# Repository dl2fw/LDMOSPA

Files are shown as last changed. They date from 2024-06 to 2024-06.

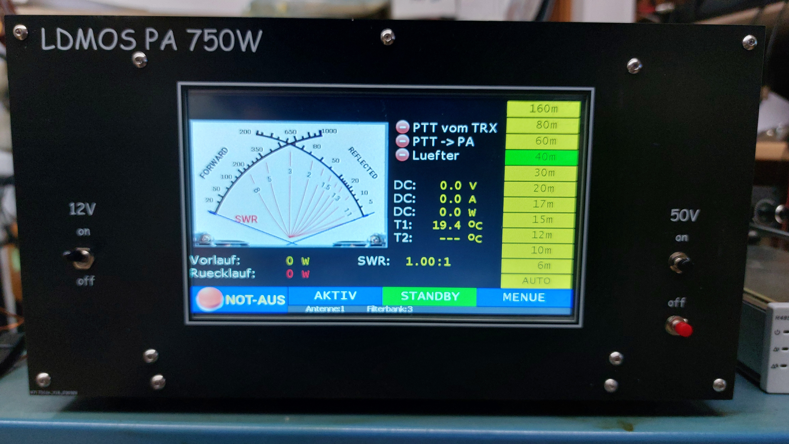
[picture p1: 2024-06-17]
images/20240617_192059.jpg

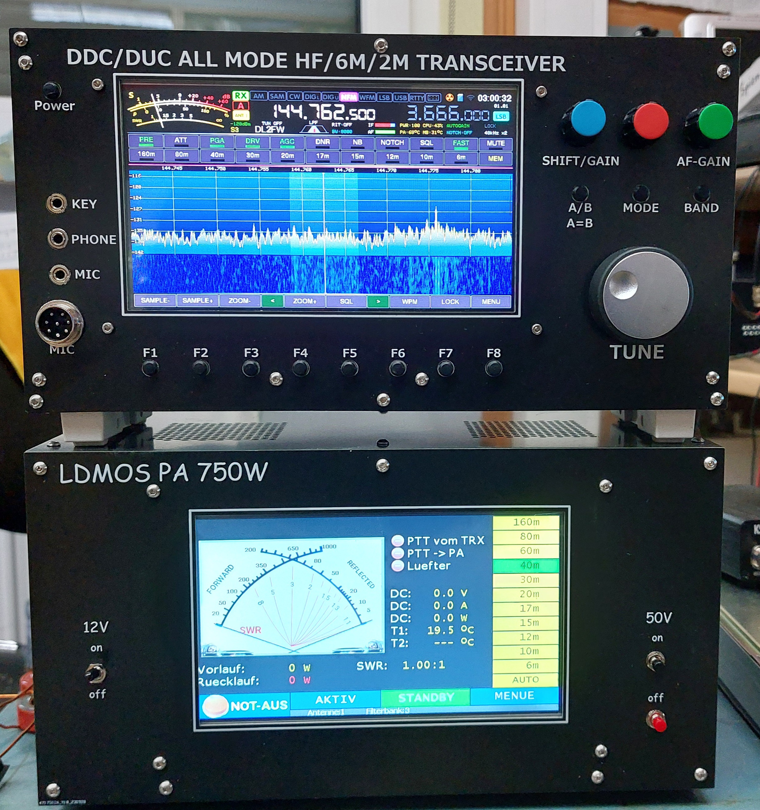
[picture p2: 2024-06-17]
images/20240617_192318.jpg

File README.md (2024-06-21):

# LDMOSPA
LDMOS PA based on the design of DJ0ABR - case from PCB Material<br>
Output power 750 or 1500 Watt - depends on if you use 1 or 2 double mosfets<br>
The PA can be either water or air cooled - the case makes both possible - I prefer the water cooled version<br>
The front has the same size as DB5AT's Wolf SDR case based on PCB Material<br>
All gerbers are available here<br>
I tried to gather all schematics and gerbers for the PA<br>
Also BOMS for Digikey, Reichelt and Aliexpress are in the BOM folder<br>
The water cooler is a ready available one (Digikey,...) for app. 65€<br>







Link to dj0abr's homepage with further information in german and english:

https://www.dj0abr.de/

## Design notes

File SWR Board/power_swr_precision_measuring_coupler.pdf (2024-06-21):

2022/01/31 19:27 | 1/14 | Power / SWR precision measuring coupler

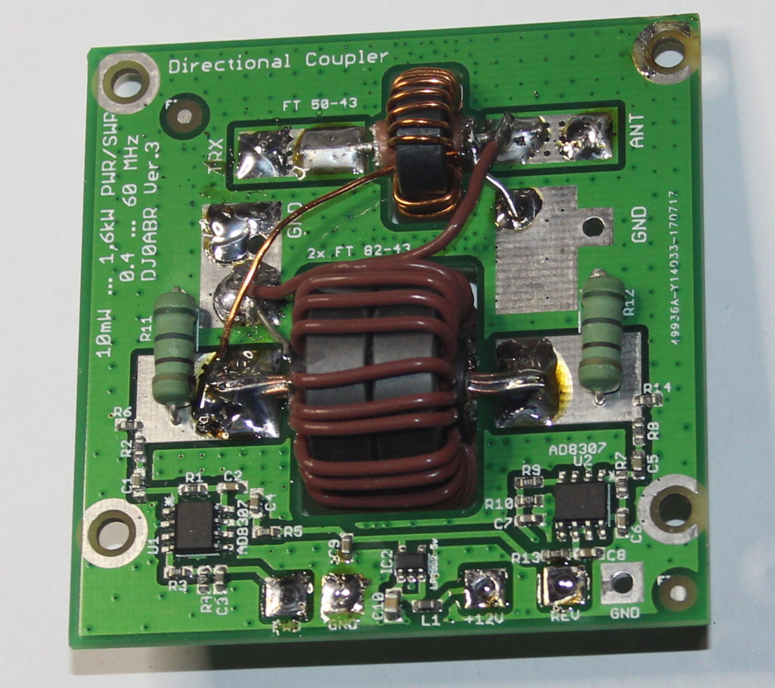
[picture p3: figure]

DJ0ABR Projects - http://projects.dj0abr.de/

# Power / SWR precision measuring coupler

0,4 ... 70 MHz

100mW ... 2kW

This second version of a Sontheimer/Frederik coupler was developed as part of our 1kW LDMOS-PA project. The focus of this coupler is a wide power range and a wide frequency range. Measurements of 1mW were omitted, but the coupler is optimized up to more than2kW, so it is well equipped for power amplifiers.

Very important was also the simple construction. The annoying mechanical work for the production of tinplate housings had to be omitted absolutely.

Technical data of this shortwave power/SWR coupler:

Power range: 100 mW to 2 kW
Frequency range: 0.4 MHz to 60 MHz (630m to 6m band), with reduced accuracy also usable in 4m band
directivity on all bands > 30dB (on 70 MHz >20dB)
built on a single board which also contains the two toroidal cores
two AD8307 are used, one for the forward power and one for the reverse power
the circuit works completely balance-free and is therefore easy to build up

the circuit of the first version turned out to be optimal, therefore it was taken over unchanged. The main changes were the mechanical construction and the dimensioning of the toroidal cores. Due to a specially calculated circuit board layout, a good adaptation could be achieved even without a housing.

The directivity and thus the resolution of the SWR measurement is so accurate that even the

Last update: 2021/05/12 16:11 | en:pwrswr:pwrswr_overview http://projects.dj0abr.de/doku.php?id=en:pwrswr:pwrswr_overview
http://projects.dj0abr.de/ | Printed on 2022/01/31 19:27

influence of adapter plugs (PL-N etc) can be measured clearly. Also the quality of coax cables can be measured. Of course, this requires a precise dummy load (with exactly 50 ohms).

toroidal cores, size:

this coupler uses 2 toroidal cores and is therefore alignment free.

Ringcore-1: this sits directly above the connection transceiver antenna. This line is passed through the core once (so means 1 turn). This core measures the current which flows from the transceiver to the antenna. In this core almost no power is converted. A tiny amount of power is coupled in through one turn and coupled out through the 24 secondary turns. Since no power is converted, this core can remain very small. We have chosen the FT50-43 from Amidon.

Ring core-2: this is connected with its 24 turns directly to the antenna output of the coupler. Depending on inductance and transmitting power a considerable current flows here which leads to a heating of this toroid due to copper and iron losses. Since the coupler should work up to 2 kW, 2 pieces of Amidon FT82-43 are glued on top of each other and wound together.

For the symmetry of the coupler only the number of turns is important (here it is 24 Wdg. each) the core size has no influence, so you can work with one FT50 and two FT82.

toroidal cores, material:

To cover such a wide range from 0.4 MHz to 60 MHz is always a compromise. There is simply no toroid that has consistent characteristics over this range.

We tested countless cores and finally decided on the Amidon Material 43. This has only a slight drop at 400 kHz, a little more drop at 52 MHz, but offers an excellent straight frequency response in the interesting range from 160m to 10m.

If you are mainly interested in the lower bands, you can use material 77, which goes well from 0.1 MHz to 21 MHz, above that it breaks in.

The 6m band takes a special position. One could still get a little more out with the material 61, however, on 50 MHz the mechanical construction already has an extreme effect. The approach of the hand to the toroidal cores already influences the measurement. Nevertheless, with material 43, we still have measurement accuracies for SWR that are better than most commercial SWR meters.

Number of turns:

basically you should use as many turns as possible, for 2 reasons: first, the precision of the coupler increases with the number of turns and second, we need as high an inductance as possible for toroid-2 so that its current drops and it gets less hot.

However, the other side of the coin is that as the number of turns increases, the upper cutoff frequency of the coupler decreases. There are also resonances between the toroidal inductance and the parasitic capacitances of the structure, which are in the range between 30 and 100 MHz. If one makes too many turns, this resonance comes down and disturbs the measurement in the 6m band. In

2022/01/31 19:27 | 3/14 | Power / SWR precision measuring coupler
many tests it has been found that 24 turns work optimally.

Measuring amplifier:

the very proven Analog Devices AD8307 is used. The achievable measuring range of less than 10mW up to more than 2kW is unbeatable. Unfortunately this IC is very expensive and is traded between 10 and 13 Eur per piece. Since I don't trust the Far East fakes, we bought a large quantity in a collective order for a quite good price, so you can get these ICs HERE quite cheap.

Circuitry of the toroidal cores:

on top is toroid-1 directly between transmitter and antenna, it measures the current through the antenna cable. The bottom core is toroid-2, it measures the voltage at the antenna connector.

Together with the 50 Ohm resistors they form the measuring bridge. The AD8307 is connected to the two output lines.

There are 56 Ohm resistors inserted. Together with the input resistance of the AD8307 circuit, the required 50 ohms are obtained. An adjustment to 50 ohms would be possible, but in practice it is not feasible because the accuracy of the usual measuring instruments is not sufficient for this. A directivity of better than 30dB can always be achieved without any adjustment and thus a SWR resolution of a few hundredths !

Winding scheme in detail:

there is nothing more confusing than the correct winding scheme. But it has to be right. The layout is set to this winding scheme, if you do it wrong then you quickly lose 10dB of directivity.

To keep the overview, here is a photo series with detail shots. This is just to show in which direction the cores are wound. If you look closely, you can see that the FT50 and FT82 cores have opposite winding directions.

Number of windings: 24 (for both cores)

Wire:

The FT50-43 is wound with CuL 0,63mm diameter (any wire between 0,35 and 0,65mm can be used)

The two FT82-43 glued together are wound with CuL 1.0mm diameter (any wire between 0.60 and 1.2mm can be used)

In the pictures the FT82-43 pair is wound with Teflon wire 0,34qmm (1mm outer diameter). This is easier than using CuL wire, because there is no danger to scratch the varnish of the wire (available here).

first the small FT50-43:

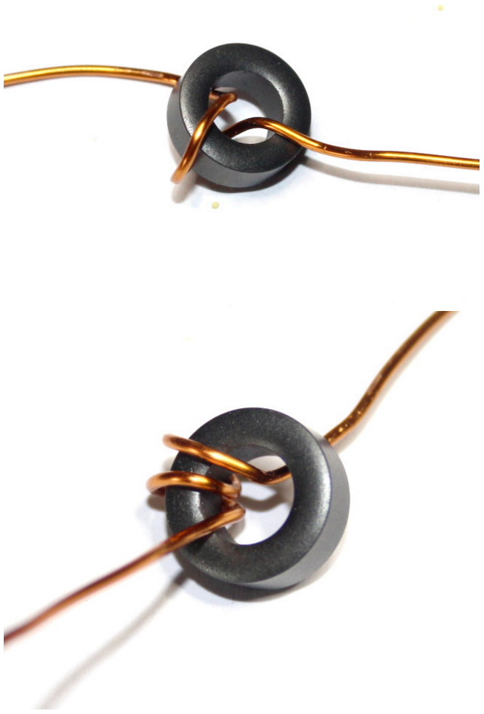
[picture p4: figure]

then the scheme for the pair FT82-43:

of course a FT82-43 double pack is wound, here for a better overview the winding scheme on a single core.

2022/01/31 19:27 | 5/14 | Power / SWR precision measuring coupler

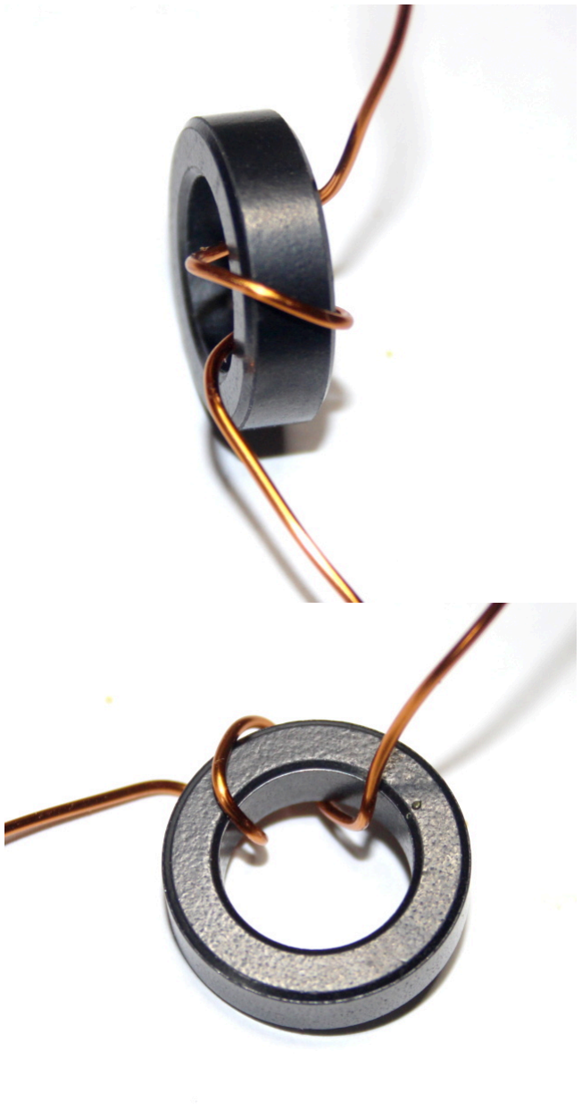
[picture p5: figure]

AD8307 Measurement circuit:

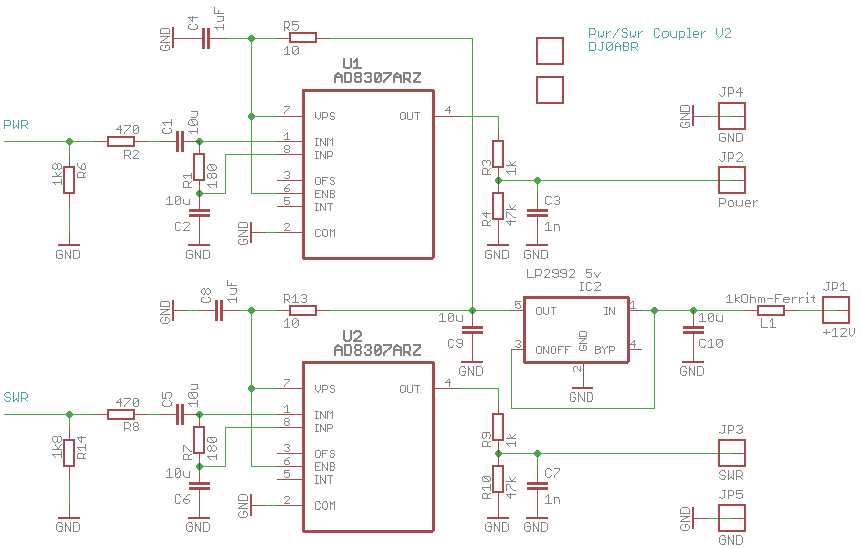
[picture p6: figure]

the 1.8kOhm resistor is in parallel with the 56 Ohm resistor (schematic above), together with R8 and the input resistor of the AD8307 you get 50 Ohm.

At the solder terminals JP2 and JP3 a voltage is output which corresponds to the forward and reverse power. This voltage is in the range of 0.5 to 2 volts and therefore fits to the different display boards.

Board and assembly diagram:

the two cutouts are used to hold the toroidal cores.

Assembly instructions:

this is how the assembled board looks like, still without toroidal cores:

2022/01/31 19:27 | 7/14 | Power / SWR precision measuring coupler

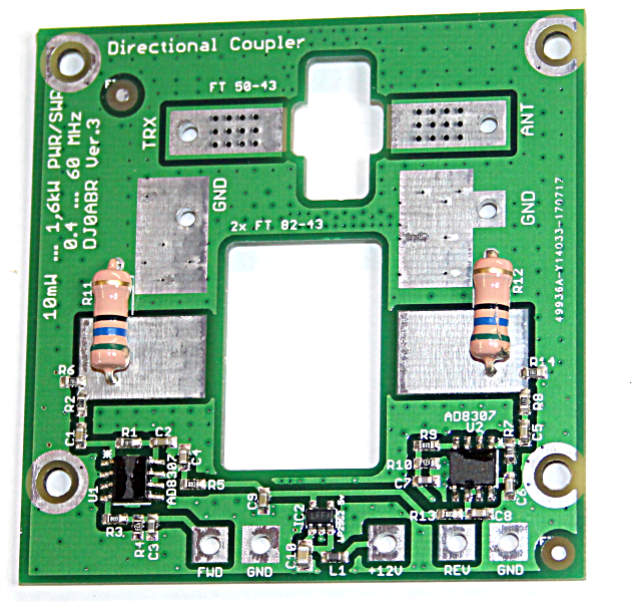
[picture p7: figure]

Preparation of the toroidal cores:

24 turns of CuL (approx.) DM 0.35 mm are wound on the FT50-43. You can use wire diameters from 0.3 to 0.65mm.

Two FT82-43 are glued together and then wound with 24 turns of CuL (approx.) DM 0.63 mm, wire diameters from 0.6 to 1.0 mm fit here.

For better shielding (only with this the coupler can be used on 6m and 4m) the wires through the toroidal cores must be made of coaxial cable. To avoid short-circuiting the voltage to be measured, the shield of this coaxial cable must be connected to ground on one side only.

Prepare the following small pieces of cable:

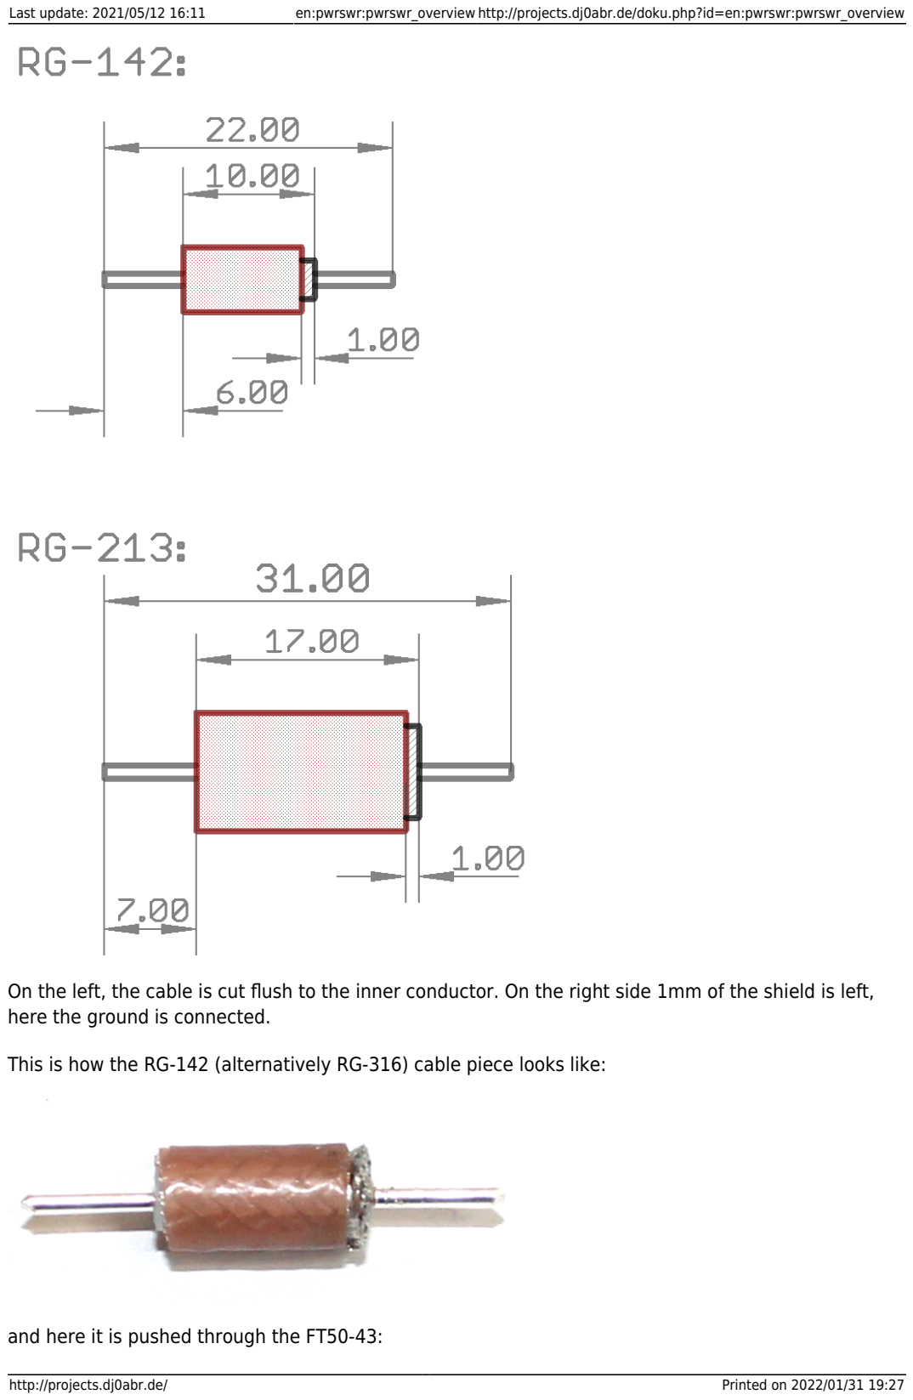
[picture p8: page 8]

On the left, the cable is cut flush to the inner conductor. On the right side 1mm of the shield is left, here the ground is connected.

This is how the RG-142 (alternatively RG-316) cable piece looks like:

and here it is pushed through the FT50-43:

2022/01/31 19:27 | 9/14 | Power / SWR precision measuring coupler

and the RG-213 (alternatively Aircell-7) cable piece:

Detail photos of the installation of the cores and their connection:

at the end of this post there are several detail photos. Please connect the cores exactly according to them.

Checking the coupler:

this coupler does not need any adjustment, because the measurement is done by the AD8307 which are very accurate. Of course the coupler has a certain division ratio which is given by the selected resistors. This ratio as well as always existing component tolerances are performed by the display boards by software.

What we still do to test the board is to measure the directivity because we want to be better than 30dB:

For this we connect

1. a 12V power supply
2. a voltmeter to the output FWD
3. a voltmeter to the output REV
4. a KW radio to the TRX connector
5. a 50 Ohm dummyload as accurate as possible to the ANT connector

the requirements for the dummy load are high, it should be in the range of 49.5 to 50.5 ohms. Mostly dummyloads are not that accurate so we will measure a worse directivity than the coupler actually offers. If you want to know exactly, you have to measure 50 Ohm resistors precisely and also know the accuracy of the ohmmeter.

To measure the directivity we proceed like this:

1. Set radio to 7MHz and transmit at 5 watts in FM (continuous carrier).
2. Measure the voltage at FWD (in millivolts).
3. Set radio to 7MHz and transmit at 100 watts in FM (continuous carrier).
4. Measure the voltage at FWD (in millivolts).
5. Measure the voltage at REV (in millivolts).

Once you have measured the three voltages, enter them into this Excel sheet and you can read the directivity. Yellow lines are to be entered, the others are calculated.

We use 7 MHz because KW dummy loads become more and more inaccurate at higher frequencies. If you use a 50 Ohm RF resistor you are better off, but measure the accuracy here too. Furthermore, the dummy load must be connected short, with a good coaxial cable and no adapter plugs may be used because all this makes the directional sharpness look worse than it is.

Note on the measurement setup:

If you want to determine the directivity of a coupler exactly, you have to meet the following requirements:

solder a 50 Ohm RF resistor directly and without cable to the output pins of the PCB (cable and connector would already have an SWR of >1.05 and would therefore falsify the measured value).
measure the 50 Ohm RF resistor (there are many resistors that have high tolerances), it should deviate by a maximum of 0.5 Ohm, but this already pushes the directivity to no 40dB. Please pay attention to the tolerance of the resistance meter.
do not hold out probes or other measuring devices, since their capacitance worsens the measurement of the directivity
if you want to measure the power at the same time, build an adapted decoupling as described in the following link

Detailed images:

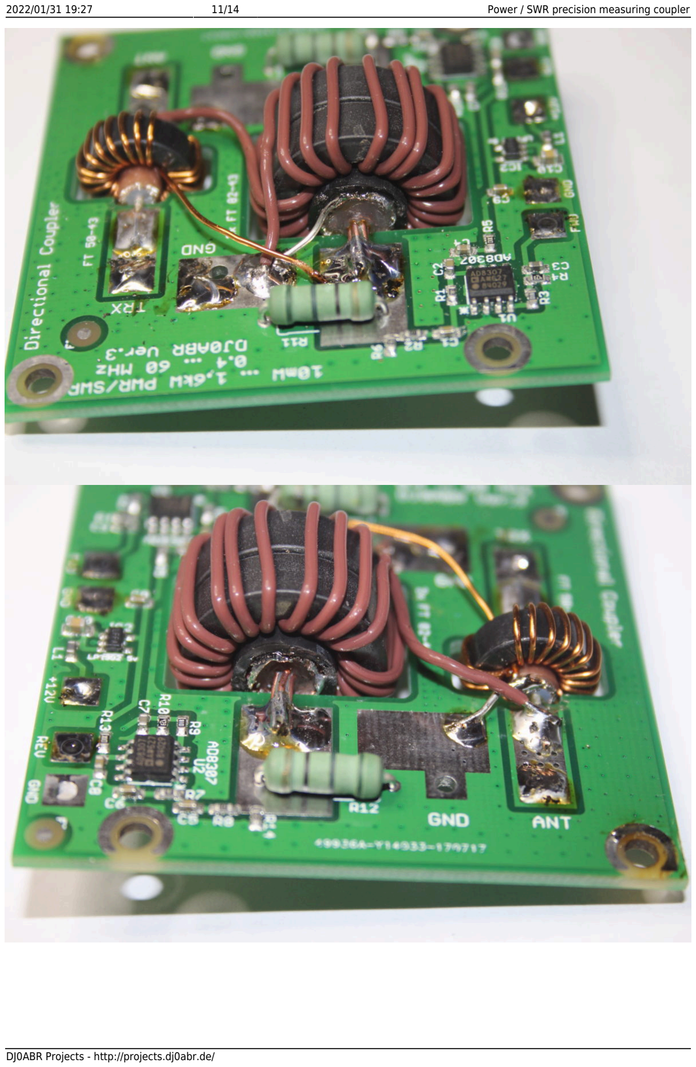
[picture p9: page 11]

2022/01/31 19:27 | 11/14 | Power / SWR precision measuring coupler

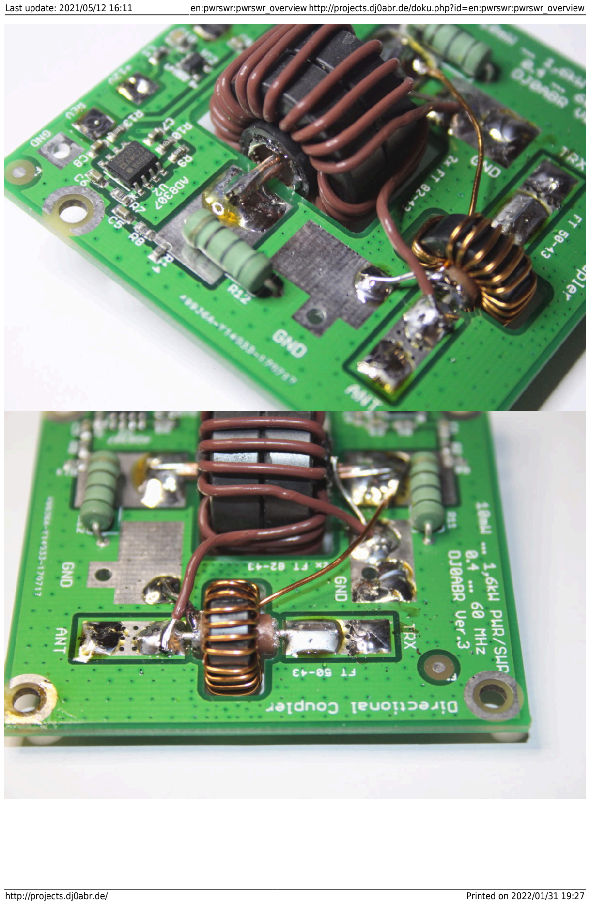
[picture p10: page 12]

2022/01/31 19:27 | 13/14 | Power / SWR precision measuring coupler

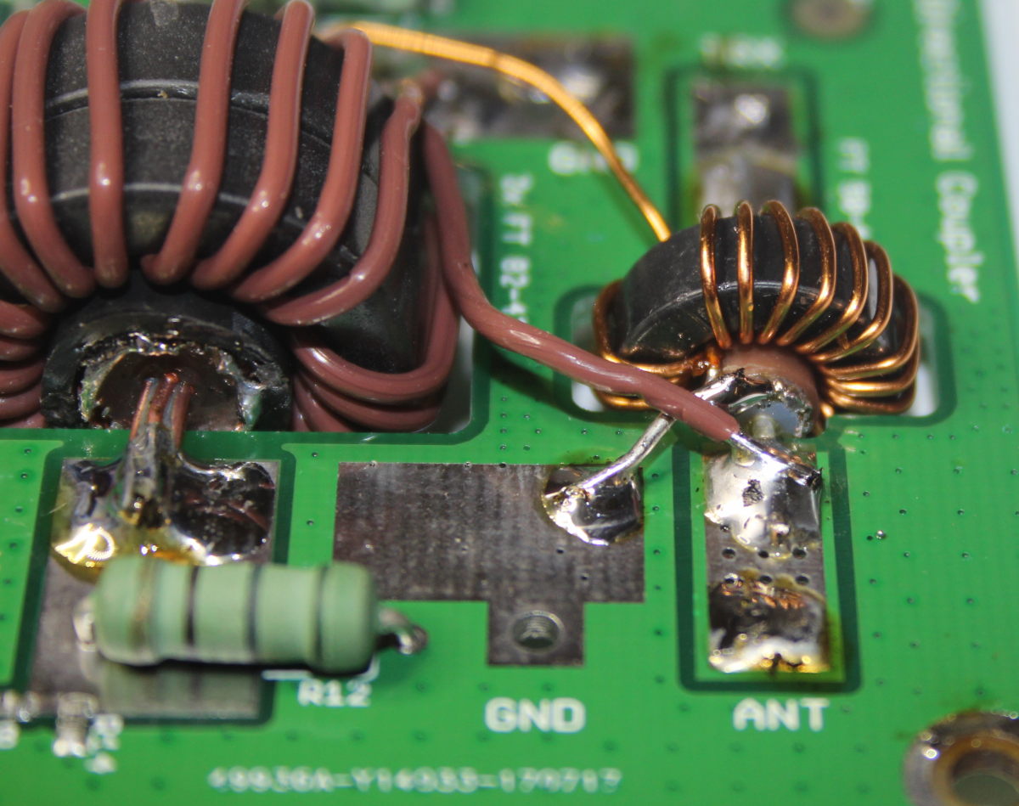
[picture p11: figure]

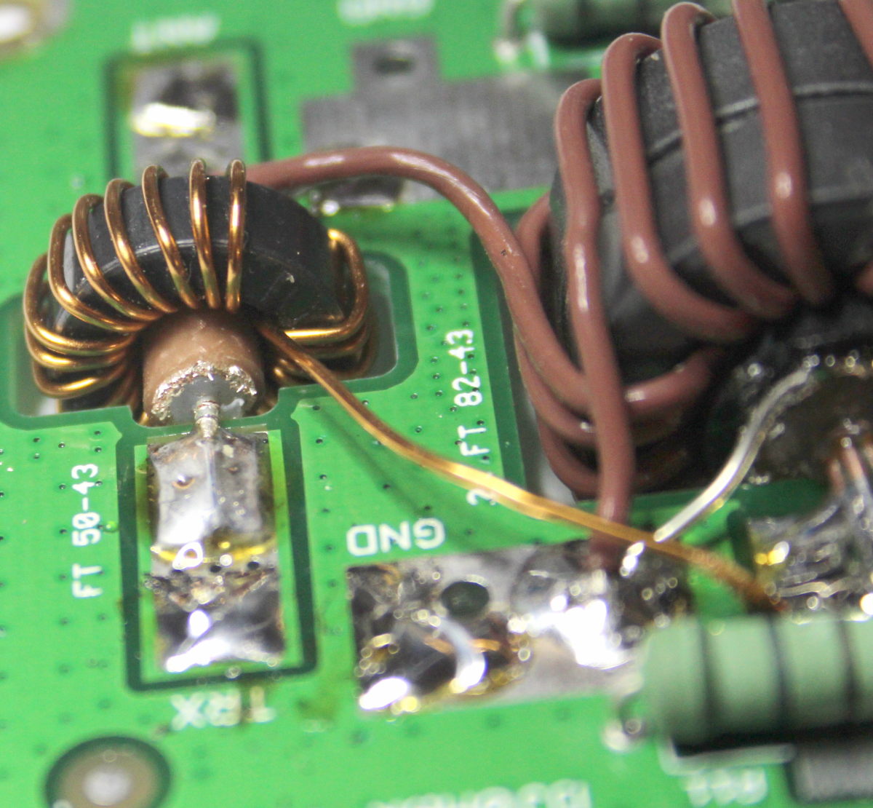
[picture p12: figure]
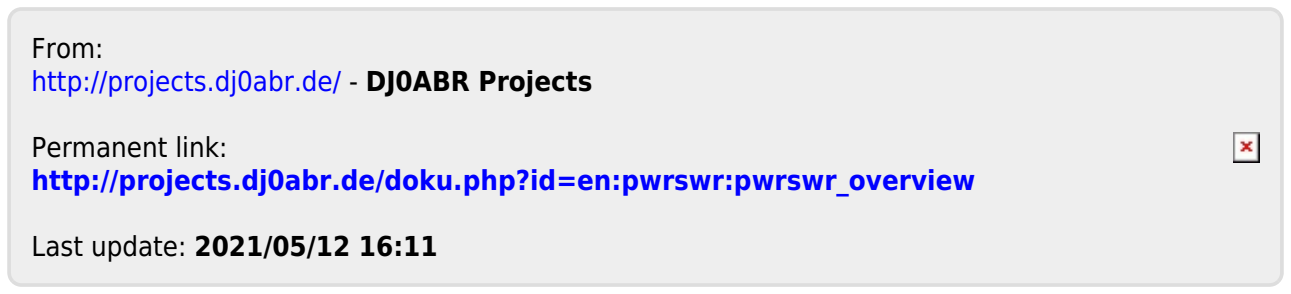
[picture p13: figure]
From: http://projects.dj0abr.de/ - DJ0ABR Projects; Permanent link: http://projects.dj0abr.de/doku.php?id=en:pwrswr:pwrswr_overview; Last update: 2021/05/12 16:11

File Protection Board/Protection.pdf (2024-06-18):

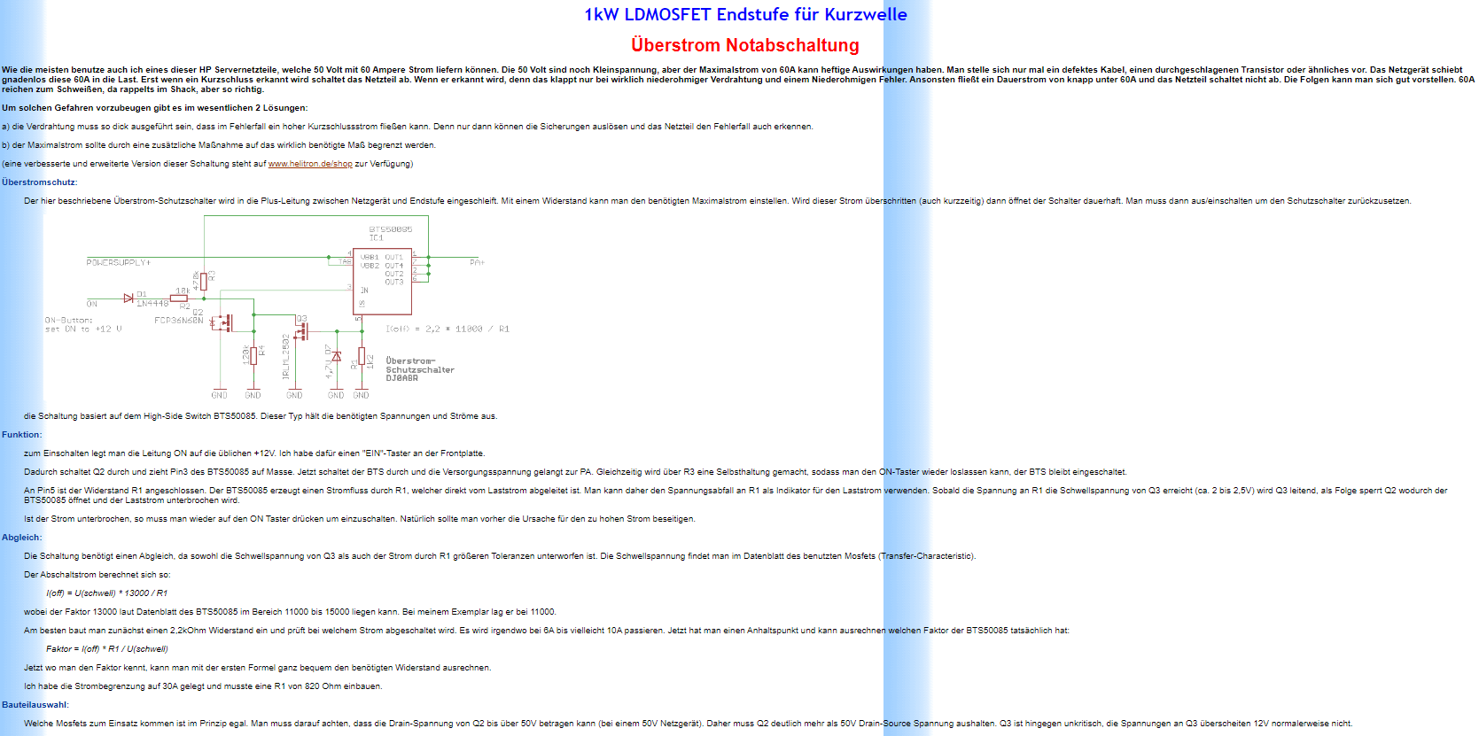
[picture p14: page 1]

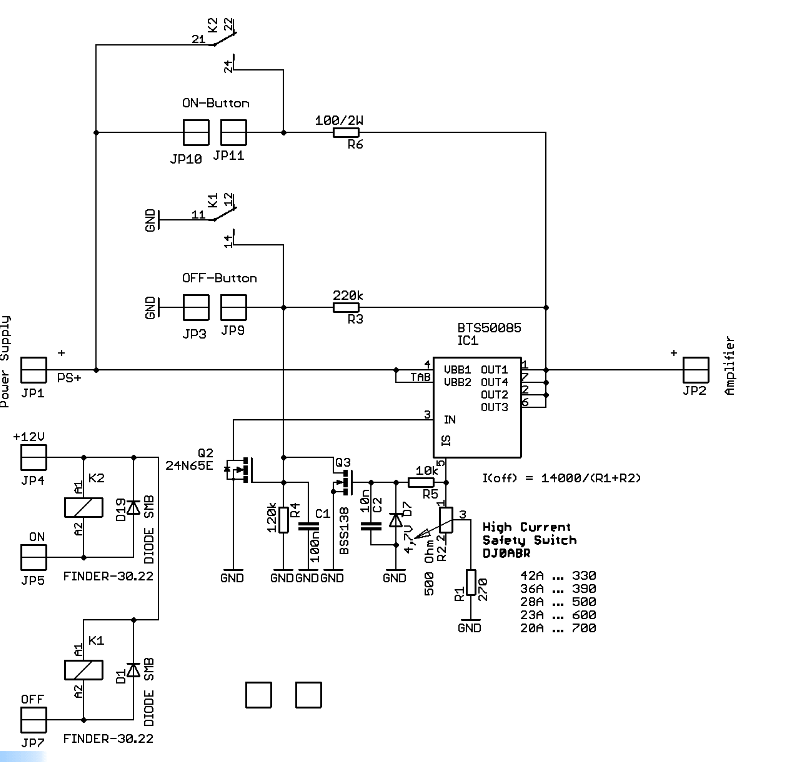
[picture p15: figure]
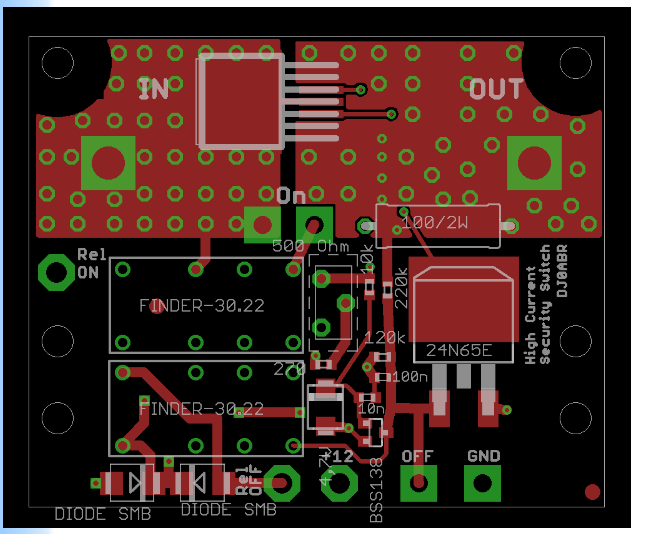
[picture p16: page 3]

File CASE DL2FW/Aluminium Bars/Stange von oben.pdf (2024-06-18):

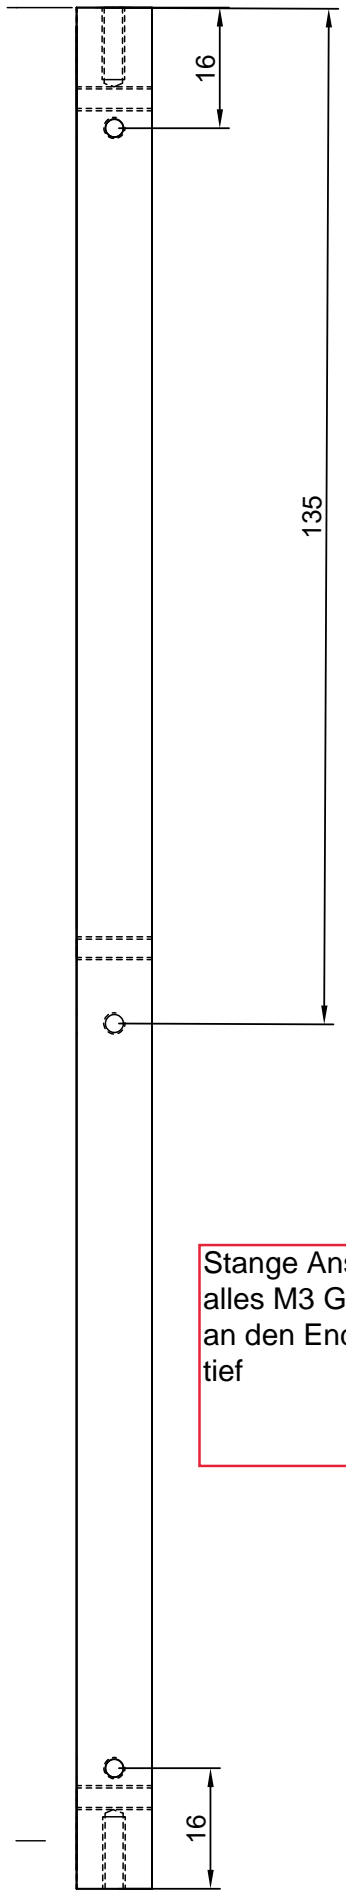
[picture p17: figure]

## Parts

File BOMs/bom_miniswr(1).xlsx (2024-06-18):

QTY |  |  |  |  |  | Reichelt | Digikey | Preis | Gesamt
1 | 10u/25 | cer. Cap. Multilayer | SMD 0805 | C10 |  | 1276-6454-1-ND |  | 0.16 | 0.16
2 | 56/2W | Resistor | 0411/12 | R11, R12 |  | 2W METALL 56 |  | 0.14 | 0.28
2 | FT82-43 | Ferrite Core |  |  | Amidon | AMI FT-82-43 |  | 2.25 | 4.5
1 | FT50-43 | Ferrite Core |  |  | Amidon | FT 50-43 |  | 0.99 | 0.99
5 | 10u | cer. Cap. Multilayer | SMD 0603 | C1, C2, C5, C6, C9 |  | KEM X5R0603 10U |  | 0.13 | 0.65
1 | LP2992 5v | voltage regulator 5V | SOT23-5 | IC2 |  | LP 2992 IM5-5.0 |  | 2.1 | 2.1
2 | AD8307ARZ | log.Amp. | SOIC8 | U1, U2 | Alieexpresss
2 | 1k | SMD resistor 0,1W | SMD 0603 | R3, R9 |  | SMD-0603 1,0K |  | 0.04 | 0.08
2 | 1k8 | SMD resistor 0,1W | SMD 0603 | R6, R14 |  | SMD-0603 1,8K |  | 0.04 | 0.08
2 | 10 | SMD resistor 0,1W | SMD 0603 | R5, R13 |  | SMD-0603 10 |  | 0.04 | 0.08
2 | 180 | SMD resistor 0,1W | SMD 0603 | R1, R7 |  | SMD-0603 180 |  | 0.04 | 0.08
2 | 470 | SMD resistor 0,1W | SMD 0603 | R2, R8 |  | SMD-0603 470 |  | 0.04 | 0.08
2 | 47k | SMD resistor 0,1W | SMD 0603 | R4, R10 |  | SMD-0603 47K |  | 0.04 | 0.08
2 | 1n | cer. Cap. Multilayer | SMD 0603 | C3, C7 |  | WAL 0603B102K500 |  | 0.02 | 0.04
2 | 1uF | cer. Cap. Multilayer | SMD 0603 | C4, C8 |  | X5R-G0603 1,0/25 |  | 0.13 | 0.26
1 | 1kOhm-Ferrit |  | SMD 0603 | L1 | or similar |  | 732-1592-1-ND | 0.16 | 0.16
1 | PCB | 62*61mm |  |  | JLCPCB |  | 5 Pieces |  | 2
 |  |  |  |  |  |  |  |  | 11.62

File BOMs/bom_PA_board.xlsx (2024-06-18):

 |  |  |  |  | Reichelt | Digikey | Preis | Summe
Qty | Device | Type | Package | Parts
2 | 250 ohms | Trimm Poti | RM 5 / 2,5mm | R16, R25 | 64Y-200 |  | 1.6 | 3.2
2 | 470uF/63V | electrolytic cap. | 12.5 (Dia.) x 20mm | C40, C41 | EB-A 470U 63 |  | 0.99 | 1.98
1 | Lesitungsrelais 12V G5RL-1E-HR-12V |  | G2RE | K3 | G5RL-1E-HR 12DC |  | 1.99 | 1.99
1 | IRLML6401 | P-CHANNEL MOS FET | SOT23 | T7 | IRLML 6401 |  | 0.82 | 0.82
1 | 10u | ceramic multilayer capacitor X7R | SMD 0603 | C48 | KEM X5R0603 10U |  | 0.13 | 0.13
3 | 10n | ceramic multilayer capacitor X7R | SMD 0603 | C6, C10, C56 | KEM X7R0603 10N |  | 0.03 | 0.09
2 | 1k | resistor | SMD 0603 | R6, R11 | SMD-0603 1,0K |  | 0.04 | 0.08
2 | 10k | resistor | SMD 0603 | R17, R18 | SMD-0603 10K |  | 0.04 | 0.08
2 | 270 | resistor | SMD 0603 | R13, R24 | SMD-0603 270 |  | 0.04 | 0.08
2 | 47 | resistor | SMD 0603 | R12, R23 | SMD-0603 47 |  | 0.04 | 0.08
2 | 470 | resistor | SMD 0603 | R7, R14 | SMD-0603 470 |  | 0.04 | 0.08
2 | 5k6 | resistor | SMD 0603 | R10, R22 | SMD-0603 5,6K |  | 0.04 | 0.08
2 | 560 | resistor | SMD 0603 | R9, R21 | SMD-0603 560 |  | 0.04 | 0.08
2 | 100u/63 | electrolytic cap. | Dia 11 max. | C20, C21 | TG-V 100U 63 |  | 1.1 | 2.2
3 | 100n | ceramic multilayer capacitor X7R | SMD 0603 | C4, C42, C54 | WAL 0603B104K500 |  | 0.02 | 0.06
5 | 1u | ceramic multilayer capacitor X7R | SMD 0603 | C3, C5, C53, C55, C57 | X5R-G0603 1,0/25 |  | 0.13 | 0.65
2 | 10u | ceramic multilayer capacitor X7R | SMD 0805 | C9, C47 | X5R-G0805 10/16 |  | 0.05 | 0.1
2 | 10n/500V | caramic capacitor 450V | SMD 1206 | C1, C2 |  | 311-1510-1-ND | 0.25 | 0.5
14 | 10n/500V | ceramic multilayer capacitor X7R | SMD 1210 | C30, C31, C32, C33, C34, C35, C36,C37, C38, C39, C43, C44, C45, C46 |  | 478-KGM32ER72H103KUCT-ND | 0.63 | 8.82
8 | 100n/600V | ceramic multilayer capacitor X7R | SMD 1812 | C12, C13, C17, C18, C49, C50, C51, C52 |  | 478-KGM43FR72J104KVCT-ND | 0.64 | 5.12
4 | 10n/1kV | ceramic multilayer capacitor X7R | SMD 1812 | C8, C11, C15, C16 |  | 1812AC103KAT1A | 0.49 | 1.96
8 | 120p/3kV | ceramic multilayer capacitor C0G | SMD 1812 | C22, C23, C24, C25, C26, C27, C28, C29 |  | CGA8L1C0G3F121K160KA | 0.75 | 6
2 | 1u/250V | ceramic multilayer capacitor X7R | SMD 1812 | C14, C19 |  | C1812X105K251T | 1 | 2
8 | DIODE SMB | standard Schottky Diode | SMB | D4, D5, D8, D9, D12, D13, D15, D16 |  | S2MFSCT-ND | 0.41 | 3.28
2 | NTC0805J5K0 | NTC | SMD 0805 | R8, R15 |  | 1712-NTC0805J5K0CT-ND | 1.2 | 2.4
12 | 10 | resistor | SMD 1206 | R26, R27, R28, R29, R30, R31, R32,R33, R34, R35, R36, R37 |  | 541-10.0UCT-ND | 0.37 | 4.44
2 | 10/2W | resistor | SMD 2512 | R4, R5 |  | A121124CT-ND | 0.62 | 1.24
1 | 100/2W | resistor | SMD 2512 | R3 |  | CRM2512-FX-1000ELFCT-N | 0.5 | 0.5
4 | 22/2W | resistor | SMD 2512 | R1, R2, R19, R20 |  | CRM2512-JW-220ELF | 0.57 | 2.28
1 | LP2992 - 5V | 5V voltage regulator | SOT23-5 | IC2 |  | LP2992AIM5X-5.0/NOPBCT-ND | 1.5 | 1.5
2 | 4,7V | zener diode | SMA | D3, D7 |  | KDZVTFTR4.7BCT-ND | 0.44 | 0.88
1 | 6,2V/1W | zener diode | SMA | D14 |  | KDZVTFTR6.2BCT-ND | 0.44 | 0.44
2 | 8,2V | zener diode | SMA | D2, D6 |  | SMAJ4738A-TPCT-ND | 0.38 | 0.76
2 | SMBJ15A | TVS protection diode | SMA | D10, D11 |  | SMBJ15ALFCT-ND | 0.37 | 0.74
1 | BLF188 | BLF188XR (or two BLF188XR) | BLF188 | T1, T2 |  | xxx |  | 0
1 | 12V Relais | Relais 12V Kontakt: DPDT |  | K2 |  | PB1632-ND | 3.85 | 3.85
8 | Ferrite Core |  | Laird 28B1020-100 |  |  | 240-2081-ND | 2.47 | 19.76
1 | Ferrite Core | Input Transformer | Laird 28B0562-100 | TR1 |  | 240-2607-ND | 0.54 | 0.54
1 | Ferrite Ring | Ub EMI suppression | any code possible Dia abt. 30mm | L1 |  | 732-1536-ND | 5.84 | 5.84
 | Water Cooler |  |  |  |  | CP4A-114B-108E-ND |  | 80.43
 | Copper Plate |  | 10mmm thick
 | Power Mosfet | BLF188 or MRFX1K80 | app. 150€
 | Board |  | Size: 116*200mm | select high copper coating! |  | from JLCPCB | 5 Pieces | 30.9
 |  |  |  |  |  |  | Sum | 188.79 | €

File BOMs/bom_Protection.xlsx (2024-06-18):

QTY |  |  |  | Reichelt | Digikey | Preis | Gesamt
1 | 270 | R0603 | R1 | SMD-0603 270 |  | 0.04 | 0.04
1 | 500 Ohm | MINIPOTI | R2 | 64Y-500 |  | 1.2 | 1.2
1 | 220k | R0603 | R3 | SMD-0603 220K |  | 0.04 | 0.04
1 | 120k | R0603 | R4 | SMD-0603 120K |  | 0.04 | 0.04
1 | 10k | R0603 | R5 | SMD-0603 10K |  | 0.04 | 0.04
1 | 100/2W | P0613/15 | R6 | 2W METALL 100 |  | 0.15 | 0.15
1 | 100n | C0603K | C1 | WAL 0603B104K500 |  | 0.04 | 0.04
1 | 10n | C0603K | C2 | KEM X7R0603 10N |  | 0.04 | 0.04
1 | 4,7V | SMA | D7 | BZV 55-C4V7 NXP |  | 0.1 | 0.1
1 | BSS138 | SOT23 | Q3 | BSS 138P NXP |  | 1 | 1
1 | 24n65e |  |  |  | 742-SIHB24N65EFT1-GE3CT-ND | 5.8 | 5.8
2 | Relais |  |  | Finder 30-22 12V
1 | BTS50085 | DPAK |  | Aliexpress, digikey,…

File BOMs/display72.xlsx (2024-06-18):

QTY | Value | Device | Package | Parts | Supplier | Order No. | Reichelt | Digikey | Preis | Gesamt
5 | 5 1N4448 | SMD Diode | SOD523 | D2, D3, D4, D5, D16 |  |  | 1N 4448W7F DII |  | 0.09 | 0.45
1 | 1 50k | MINIPOTI-S | MINIPOTI | R90 |  |  | 64Y-50K |  | 1.6 | 1.6
4 | 1 Pinheader 2x4 | Pinheader 2x4 | RM 2,54 | JP7 |  |  | BKL 10120173 |  | 1 | 4
4 | 1 Pinheader 1x6 | Pinheader 1x6 | RM 2,54 | ST3 |  |  | BKL 10120513 |  | 1 | 4
1 | Connector 2x20 | Fischer | DSP1 1 |  |  |  | BKL 10120963 |  | 1.8 | 1.8
1 | 100u/16 | electrolytic capacitor | E2,5-7 | C1 |  |  | HA-V 100U 16 |  | 0.5 | 0.5
7 | 7 N-CH_MOSFET | standard Nch Mosfet (Vgs must be <= 2.5v, so it switches with 3,3v logic. Example: IRLML2502) | SOT23 | Q2, Q3, Q10, Q13, Q14, Q15, Q16 |  |  | IRLML 2502 |  | 0.27 | 1.89
5 | 5 10u | standard chip capacitor | SMD 0603 | C6, C7, C8, C46, C50 |  |  | KEM X5R0603 10U |  | 0.13 | 0.65
14 | 14 10n | standard chip capacitor | SMD 0603 | C5, C33, C34, C35, C36, C37, C38, C49, C51, C52, C85, C86, C87, C89 |  |  | KEM X7R0603 10N |  | 0.03 | 0.42
1 | 1 MAX3232 | RS232 driver | SO16 | IC12 |  |  | MAX 232 CSE SMD |  | 1.39 | 1.39
1 | 1 OKI-78SR-5/1.5-W36H-C | 12V→5V switching reg. | THT 3pin | IC2 |  |  | R-78B50-15L |  | 14 | 14
19 | 19 1k | 0,1W standard SMD resistor | SMD 0603 | R32, R33, R43, R45, R46, R47, R48, R49, R50, R76, R77, R78, R79, R80, R81, R89, R110, R112, R114 |  |  | SMD-0603 1,0K |  | 0.04 | 0.76
1 | 1 1M | 0,1W standard SMD resistor | SMD 0603 | R35 |  |  | SMD-0603 1,0M |  | 0.04 | 0.04
8 | 8 100 | 0,1W standard SMD resistor | SMD 0603 | R4, R5, R6, R7, R8, R9, R39, R91 |  |  | SMD-0603 100 |  | 0.04 | 0.32
12 | 12 100k | 0,1W standard SMD resistor | SMD 0603 | R40, R41, R53, R54, R55, R56, R58, R59, R95, R109, R111, R113 |  |  | SMD-0603 100K |  | 0.04 | 0.48
11 | 11 10k | 0,1W standard SMD resistor | SMD 0603 | R30, R31, R34, R82, R88, R96, R97, R98, R99, R100, R115 |  |  | SMD-0603 10K |  | 0.04 | 0.44
1 | 1 2k2 | 0,1W standard SMD resistor | SMD 0603 | R102 |  |  | SMD-0603 2,2K |  | 0.04 | 0.04
1 | 1 220 | 0,1W standard SMD resistor | SMD 0603 | R25 |  |  | SMD-0603 220 |  | 0.04 | 0.04
1 | 1 22k | 0,1W standard SMD resistor | SMD 0603 | R75 |  |  | SMD-0603 22K |  | 0.04 | 0.04
1 | 1 680 | 0,1W standard SMD resistor | SMD 0603 | R103 |  |  | SMD-0603 680 |  | 0.04 | 0.04
2 | 2 8k2 | 0,1W standard SMD resistor | SMD 0603 | R85, R86 |  |  | SMD-0603 8,2K |  | 0.04 | 0.08
5 | 5 SS110B | SMD Diode | MELF | D9, D10, D11, D12, D13 |  |  | SS 110 (https://www.reichelt.de/schottkydiode-100-v-1-a-do-214ac-sma-ss-110-p146603.html?&trstct=pos_0&nbc=1) |  | 0.21 | 1.05
6 | 6 1n | standard chip capacitor | SMD 0603 | C53, C56, C59, C111, C112, C113 |  |  | WAL 0603B102K500 |  | 0.02 | 0.12
57 | 57 100n | standard chip capacitor | SMD 0603 | C9, C10, C11, C12, C13, C14, C15, C16, C17, C18, C19, C20, C21, C22, C23, C24, C25, C26, C27, C30, C55, C60, C62, C67, C68, C69, C70, C71, C72, C73, C75, C76, C77, C78, C79, C80, C90, C91, C92, C93, C94, C95, C96, C97, C98, C99, C100, C101, C102, C103, C104, C105, C106, C107, C108, C118, C119 |  |  | WAL 0603B104K500 |  | 0.02 | 1.14
14 | 14 1u | standard chip capacitor | SMD 0603 | C31, C32, C39, C40, C41, C42, C43, C44, C45, C47, C48, C61, C63, C74 |  |  | X5R-G0603 1,0/25 |  | 0.13 | 1.82
9 | 9 1u | standard chip capacitorK | SMD 0603K | C54, C57, C58, C64, C65, C81, C82, C83, C84 |  |  | X5R-G0603 1,0/25 |  | 0.1 | 0.9
6 | 6 10u | standard chip capacitor | C0805 | C2, C3, C4, C29, C116, C117 |  |  | X5R-G0805 10/16 |  | 0.05 | 0.3
1 | 1 10u | standard chip capacitor | C0805K | C88 |  |  | X5R-G0805 10/16 |  | 0.05 | 0.05
1 | 1 OSC 8MHz | Standard 8 MHz crystal oscillat | 7x5mm | OSC1 |  |  | XO91 8,00000 |  | 1.6 | 1.6
1 | 1 10k/0,1% | 0,1W standard SMD resistor | SMD 0603 | R87 |  |  |  | CRT0603-BY-1002ELF | 0.35 | 0.35
34 | 34 1kOhm-Ferrit | 0,1W standard SMD resistor | SMD 0603 | R1, R2, R3, R10, R11, R12, R13, R14, R15, R16, R17, R18, R19, R20, R21, R22, R23, R24, R62, R63, R64, R65, R66, R67, R68, R69, R70, R71, R72, R73, R92, R93, R94, R101 |  |  |  | 732-1592-1-ND | 0.16 | 5.44
2 | 2 390k/0,1% | 0,1W standard SMD resistor | SMD 0603 | R83, R84 |  |  |  | YAG4542CT-ND | 0.3 | 0.6
4 | 4 NTS245SFT1G | SMD Diode | SOD-123FL | D6, D7, D14, D15 |  |  |  | 1727-7479-1-ND | 0.4 | 1.6
1 | 1 IRLML6401 | standard Pch Mosfet (Vgs must be <= 2.5v, so it switches with 3,3v logic. Example: IRLML6401) | SOT23 | Q1 |  |  |  | 785-1001-1-ND | 0.42 | 0.42
1 | INA193AQDBVRQ1 | SOT23-5 |  | IC4 |  |  |  | 296-21443-1-ND | 2.9 | 2.9
5 | 5 IRF3704S | IRF3704S) | D2PACK | Q5, Q6, Q7, Q8, Q9 |  |  |  | IRFS3806TRLPBFCT-ND | 1.29 | 6.45
2 | 2 150141M173100 | Full Color Led | PLCC4 | LED1, LED2 |  |  |  | 732-4998-1-ND | 0.54 | 1.08
5 | 5 TS27L2C | low power OP amp | SO08 | IC5, IC6, IC7, IC8, IC9 |  |  |  | TS27L2CDT | 0.93 | 4.65
1 | 1 LF33CDT-DPAK | 3,3v LDO regulator | DPACK | IC1 |  |  |  | 497-1532-1-ND | 1.46 | 1.46
1 | 1 ADR381 | voltage reference | SOT23 | IC11 |  |  |  | 505-ADR381ARTZ-R2CT-ND | 3.39 | 3.39
5 | 5 100n/200V | standard chip capacitor | C1206K | C28, C109, C110, C114, C115 |  |  |  | 732-12081-1-ND | 0.15 | 0.75
1 | 1 4u7 | standard chip capacitor | SMD 0603 | C66 |  |  |  | 1276-1044-1-ND | 0.09 | 0.09
1 | 1 STM32F427VGT6 or STM32F427VIT6 | uController | LQFP100 | IC13 |  |  |  | 497-14049-ND | 17 | 17
1 | 1 TC7662AEPA | Voltage Converter | SO-8 | U1 |  |  |  | TC7662BCOA713CT-ND | 2.35 | 2.35
1 | 1 TL081D | Op Amp | SO08 | IC10 |  |  |  | 497-2208-1-ND | 0.53 | 0.53
1 | 1 LP2992 3v3 | 3,3v LDO regulator | SOT23-5 | IC3 |  |  |  | 296-43238-1-ND | 1.27 | 1.27
1 | 1 WE74451147/47uH | EMI inductor | optional | L1 |  |  |  | 732-1411-1-ND | 2.05 | 2.05
1 | Shunt |  |  |  |  |  |  | 650FPR002E-ND |  | 12
1 | TFT Display | 7 "zoll TFT LCD modul 800x480 SSD1963 Touch PWM AVR PC Controller Modul Für Arduino |  |  | Eckstein-shop.de | CP11013 |  |  | 70 | 70
1 | 1 DSP 7.2 PCB |  |  |  | jlcpcb |  |  | 5 Piece |  | 35.3
 |  |  |  |  |  |  |  |  |  | 209.64
1 | 1 1N4001 | SMD Diode | MELF | D1 |  |  | ok |  |  | 0
1 | ESP-07S (ESP8266) |  |  | MOD1 |  |  | ok |  |  | 0
 | Board | Size: 124*197mm

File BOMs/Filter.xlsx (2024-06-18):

 |  |  |  |  |  |  | Reichelt | Digikey |  | Summe
Qty | Value | Device | Package | Parts |  | Order No.
6 | T200-2 (130-2 for 750W) | Amidon Core |  | L16, L17, L18, L20, L21, L22 |  |  | T 130-2 |  | 4.4 | 26.4
5 | T200-6 (130-2 for 750W) | Amidon Core |  | L7, L10, L13, L14, L15 |  |  | T 130-6 |  | 7.35 | 36.75
 |  |  |  |  |  |  |  |  |  | 0
12 | G5RL-1E-HR-12V | G2RE | G2RE | K1, K2, K3, K4, K5, K6, K7, K8, K9, K10, K11, K12 |  |  | G5RL-1E-HR 12DC |  | 1.99 | 23.88
1 | Pinheader 8x1 |  |  | JP7 |  |  | MPE 087-1-036 |  | 0.62 | 0.62
10 | copper wire dia=1.5mm |  |  | enamelled copper wire |  |  |  |  |  | 0
7 | copper wire dia=2.0mm |  |  | enamelled copper wire |  |  |  |  |  | 0
4 | 6n8 | FKP1 Cap. 1,6KV | C225-074X268 | C18, C19, C20, C21 |  |  | FKP1-1600 6,8N |  | 0.53 | 2.12
2 | 470p | FKP1 Cap. 2KV | C150-064X183 | C10, C13 |  |  | FKP1-2000 470P |  | 0.27 | 0.54
2 | 680p | FKP1 Cap. 2KV | C150-064X183 | C31, C34 |  |  | FKP1-2000 680P |  | 0.22 | 0.44
6 | 1n | FKP1 Cap. 2KV | C225-062X268 | C14, C17, C32, C33 |  |  | FKP1-2000 1,0N |  | 0.49 | 2.94
2 | 1n5 | FKP1 Cap. 2KV | C225-074X268 | C35, C38 |  |  | FKP1-2000 1,5N |  | 0.55 | 1.1
4 | 2n2 | FKP1 Cap. 2KV | C225-074X268 | C11, C12, C36, C37 |  |  | FKP1-2000 2,2N |  | 0.64 | 2.56
4 | 3n3 | FKP1 Cap. 2KV | C225-074X268 | C15, C16 |  |  | FKP1-2000 3,3N |  | 0.44 | 1.76
 |  |  |  |  |  |  |  |  |  | 0
18 | 100n | SMD capacitor | C0603K | C43, C44, C45, C46, C47, C48, C49, C50, C51,
 |  |  |  | C52, C53, C54, C55, C56, C57, C64, C65, C67 |  |  | WAL 0603B104K500 |  | 0.02 | 0.36
 |  |  |  | C22, C23, C24, C25, C27, C28, C29, C30, C58, |  |  |  |  |  | 0
 |  |  |  | C59, C62, C63, C66, C72, C80, C81, C82, C83, |  |  |  |  |  | 0
23 | 10p | SMD capacitor | C1812K | C85, C91, C97, CE1, CE2 |  |  |  | CC1812JKNPOEBN100 | 1.11 | 25.53
6 | 15p | SMD capacitor | C1812K | C68, C71, C79, C84, C86, C87 |  |  |  | HV1812A150JXHATHV | 0.9 | 5.4
 |  |  |  | C1, C2, C3, C4, C5, C6, C26, C60, C61, C69, C70, |  |  |  |  |  | 0
 |  |  |  | C73, C74, C75, C76, C77, C78, C90, C94, C95, |  |  |  |  |  | 0
23 | 22p | SMD capacitor | C1812K | C96, C100, C101 C89, C92, C93, C98, C99, C102, Rs-online C7, C8, C9, C88, |  |  |  | CC1812JKNPOEBN220 | 1.11 | 25.53
 |  |  |  | C103, C104, C105, C106, C107, C108, C109, |  |  |  |  |  | 0
 |  |  |  | C110, C111, C112, C113, C114, C115, C116, |  |  |  |  |  | 0
25 | 47p | SMD capacitor | C1812K | C117 |  |  |  | 1812HA470JAT1A | 0.79 | 19.75
 |  |  |  | R2, R4, R5, R8, R9, R12, R13, R16, R17, R20, |  |  |  |  |  | 0
12 | 10ohm | SMD resistor | R0603 | R21, R24 |  |  | SMD-0603 10 |  | 0.04 | 0.48
6 | 1k | SMD resistor | R0603 | R3, R7, R11, R15, R19, R23 |  |  | SMD-0603 1,0K |  | 0.04 | 0.24
6 | 100k | SMD resistor | R0603 | R1, R6, R10, R14, R18, R22 |  |  | SMD-0603 100K |  | 0.04 | 0.24
 |  |  |  | D1, D2, D3, D4, D5, D6, D7, D8, D9, D10, D11, |  |  |  |  |  | 0
12 | SS110B | Schottky Diode | DO214-AA | D15 |  |  | SS 110 |  | 0.21 | 2.52
6 | IRLML2502 | BS170_SMD | SOT23 | Q1, Q2, Q3, Q4, Q5, Q6 |  |  | IRLML 2502 |  | 0.27 | 1.62
1 | PCB
 | Board | Size: 218*187 mm | high copper thickness! |  | JLCPCB |  |  | 5 Piece |  | 39.6
 |  |  |  |  |  |  |  |  | Sum | 220.38 | €

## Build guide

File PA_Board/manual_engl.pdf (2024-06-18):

# 1kW LDMOS Power Amplifier

Autor: Kurt Moraw, DJ0ABR
Bezugsquelle: www.helitron.de

Overview:

All information, schematics, BOM and other documents can be downloaded from www.dj0abr.de Chapter „SW LDMOS PA“.

Schematics as well as the PCB are divided in two parts, the input circuit and the output circuit. The PCB is manufactured as a single board. After soldering of the SMD parts it is divided into two parts.

You can also download this document with color pictures which is easier to read than the black and white print.

Many videos about this amplifier are available at youtube: follow the video link in chapter “SW LDMOS PA” on www.dj0abr.de folgen. The video showing the assembly of the board is: „2x BLF188XR Amp with WATERCOOLING (Part-2)“ .

SMD assembly:

if you ordered a PCB without SMD parts then first solder all SMD parts to the PCB. This picture shows the SMD assembled board:

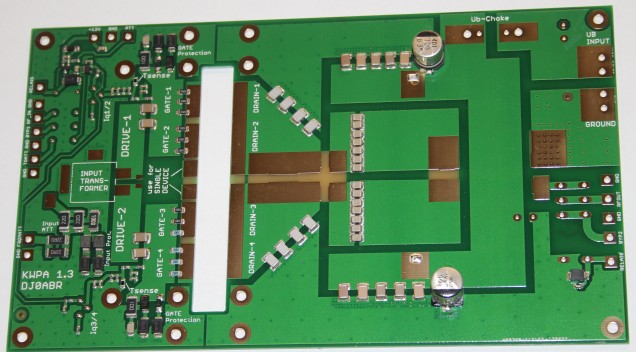
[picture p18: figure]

Now we separate the input and output parts. The red lines show where to cut the PCB (4 cuts).

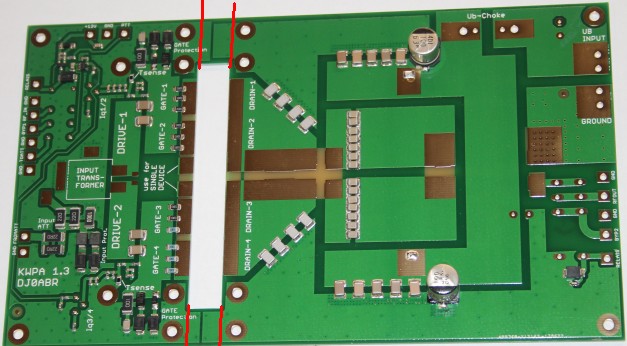
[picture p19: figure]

Assembly is made in this order:

1. Planing of the heat spreader by the help of the empty PCB and the drawing at the end of this document.
2. Assembly of all through hole parts (not the ferrite cores !)
3. Manufacturing of the copper heat spreader
4. solder the LDMOS Transistors (or two of them) to the heat spreader
5. mount the PCB to the heat spreader
6. manufacture the ferrite cores and solder it to the board
7. wiring and testing the board

Assembly of through hole parts:

assemble (see BOM):
2 Relais, two trimmers 250 Ohm, two 470uF/63V electr.Caps

Input ferrite core:

it is a 4:1 transformer. These pictures show how it is made and how to solder it to the board:

a piece of RG-316 coaxial cable it wound to the Laird 28B0562-100.

Prepare the coaxial cable (in mm):

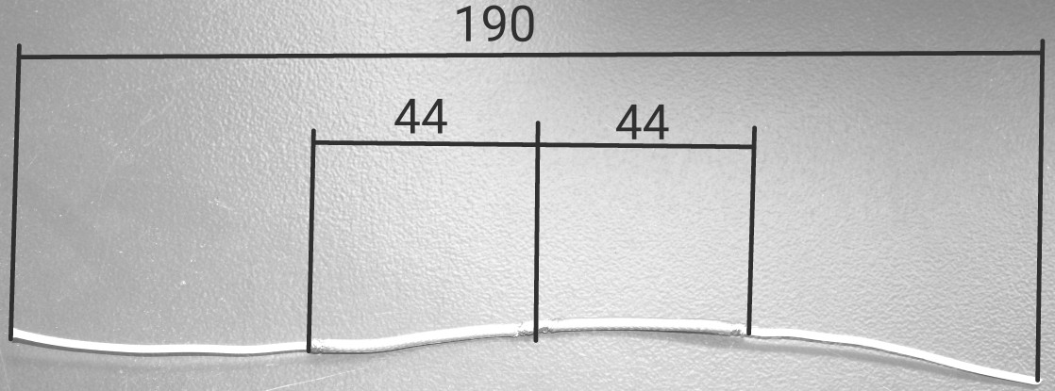
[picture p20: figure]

* take a pice of RG-316, total length 190mm
* remove 5mm of the coating exactly in the middle, leave the shield intakt and tin the shield
* remove coating and shield 44mm at the left and right as shown in the picture
* remove 3mm of the coating of the 44mm parts and tin the shield.

Now wrap the cable through the core as shown here. Solder the tinned shield in the middle of the cable to the board:

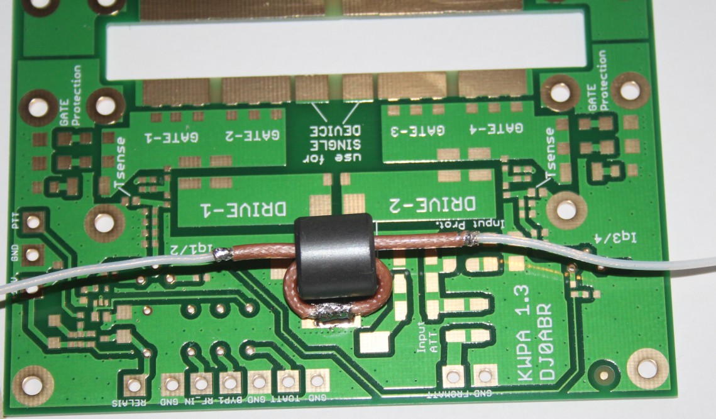
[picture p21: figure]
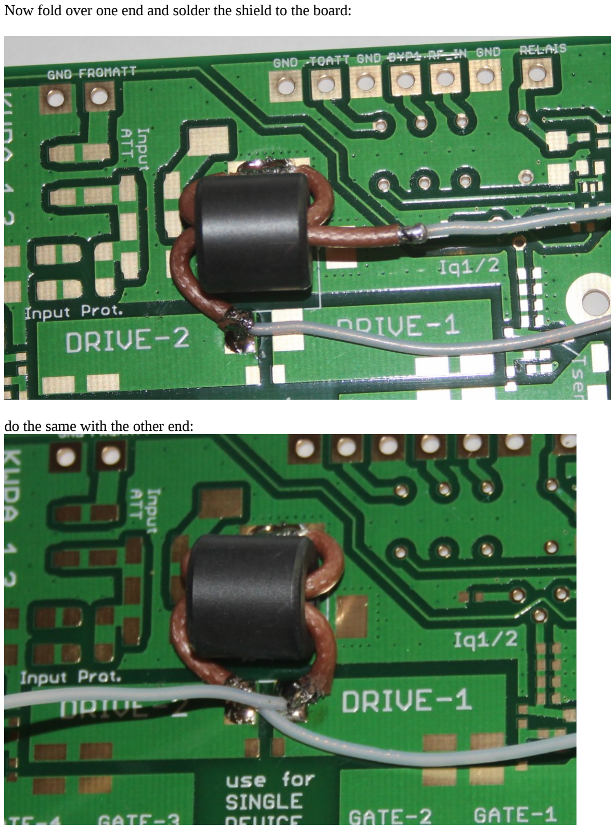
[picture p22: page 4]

Now fold over one end and solder the shield to the board:

do the same with the other end:

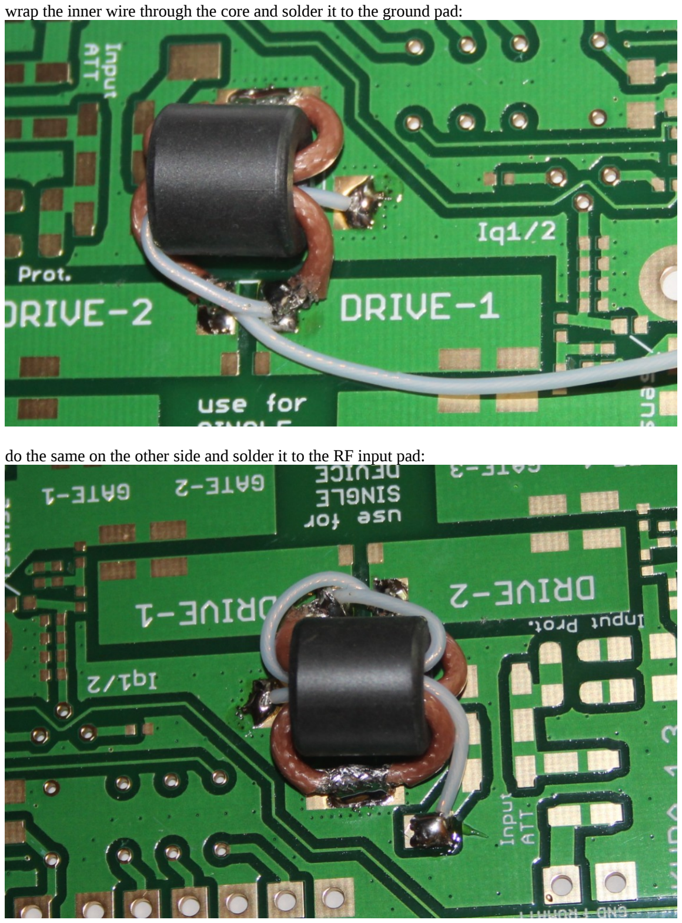
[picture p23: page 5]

wrap the inner wire through the core and solder it to the ground pad:

do the same on the other side and solder it to the RF input pad:

two output transformers:

You can use one or two cores, I have tested both versions and one core works up to 1kW. But these ferrite cores are really cheap so its better to use two cores and never get any temperature problems.

Two pieces of RG-316 are would in parallel to a Laird 28B1020-100 ferrite. This results in an impedance of 25 ohm. The length of these cables is about 500mm:

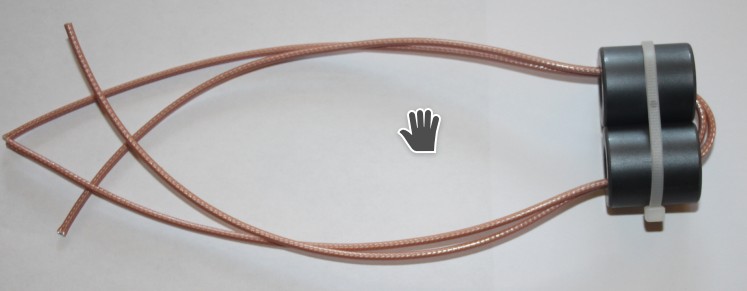
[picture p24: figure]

Use cable ties to fix the two cores, then wrap the (double) RG-316 trough the core.

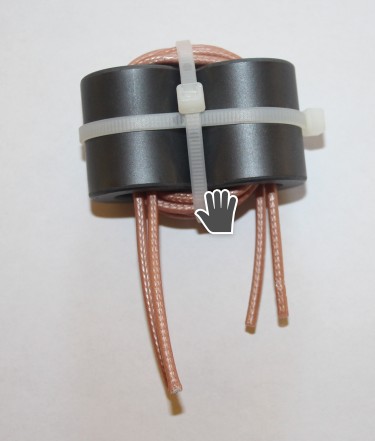
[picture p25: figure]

thread it through the core, 4 windings.

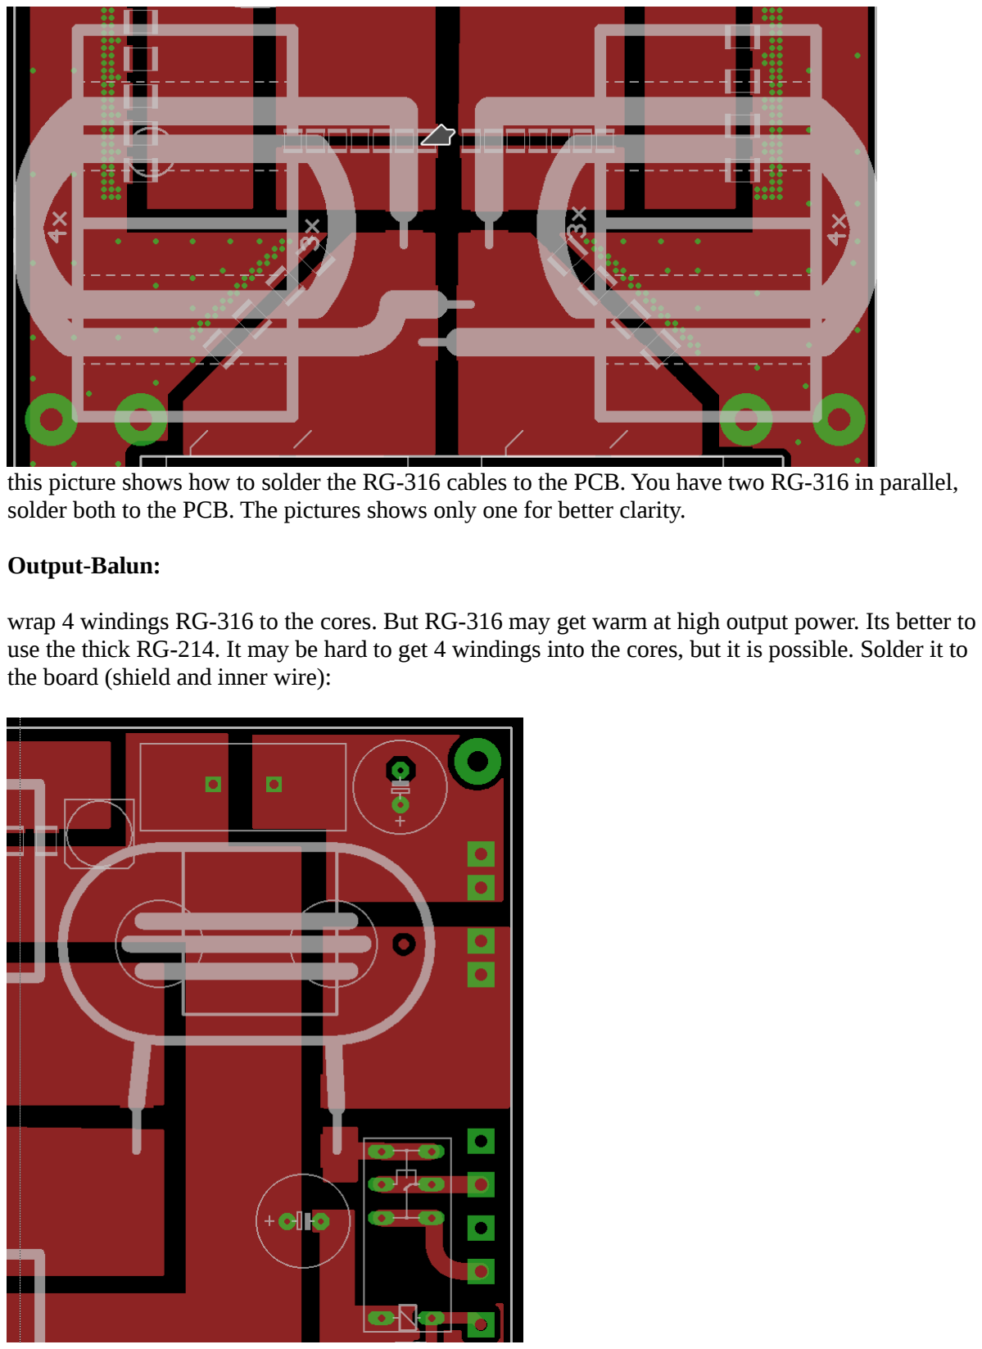
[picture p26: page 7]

this picture shows how to solder the RG-316 cables to the PCB. You have two RG-316 in parallel, solder both to the PCB. The pictures shows only one for better clarity.

Output-Balun:

wrap 4 windings RG-316 to the cores. But RG-316 may get warm at high output power. Its better to use the thick RG-214. It may be hard to get 4 windings into the cores, but it is possible. Solder it to the board (shield and inner wire):

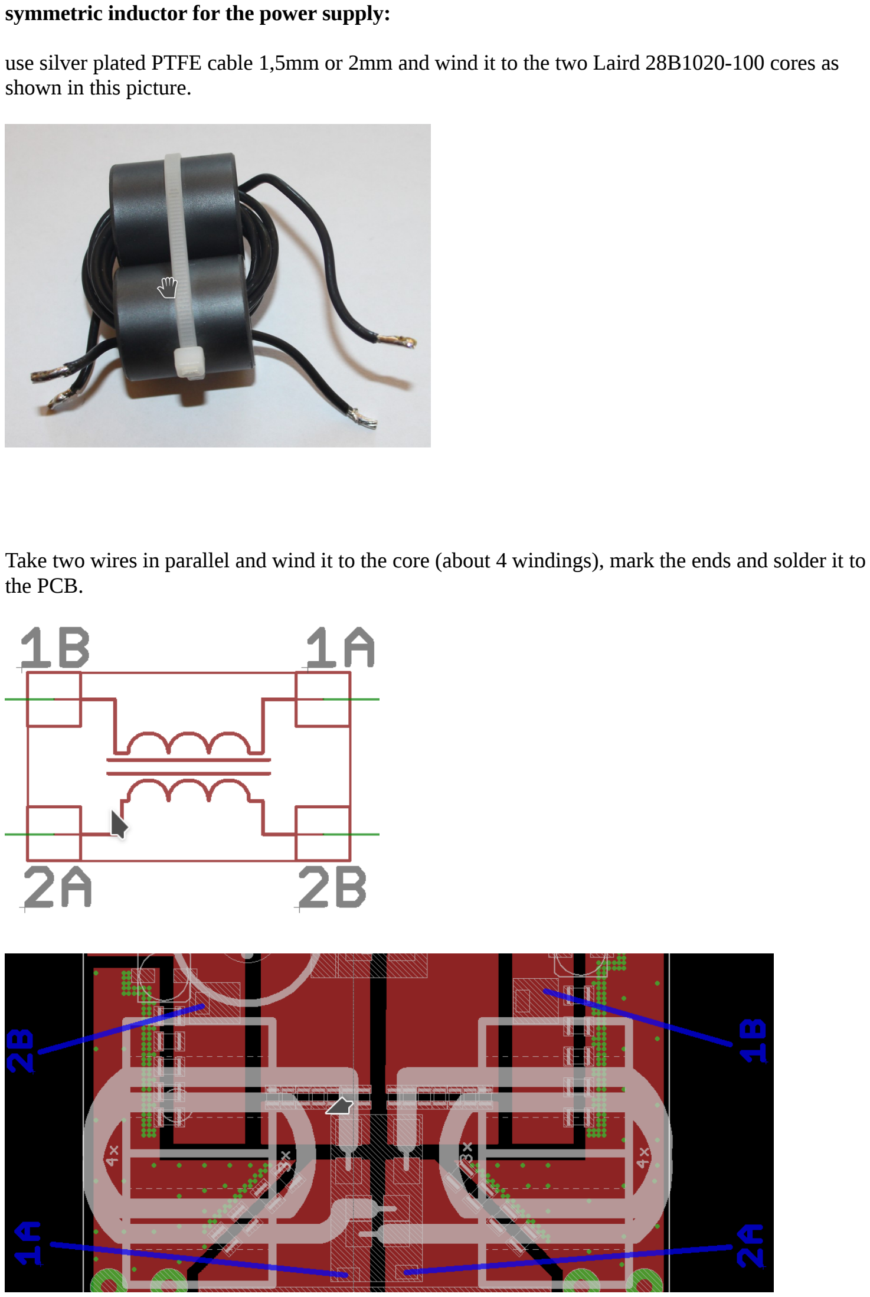
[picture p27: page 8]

symmetric inductor for the power supply:

use silver plated PTFE cable 1,5mm or 2mm and wind it to the two Laird 28B1020-100 cores as shown in this picture.

Take two wires in parallel and wind it to the core (about 4 windings), mark the ends and solder it to the PCB.

Supply-Choke:

simply use one Laird core and wind a PTFE cable 1,5 or 2mm on this core, about 5 windings.

If all cores are mounted it looks like that:

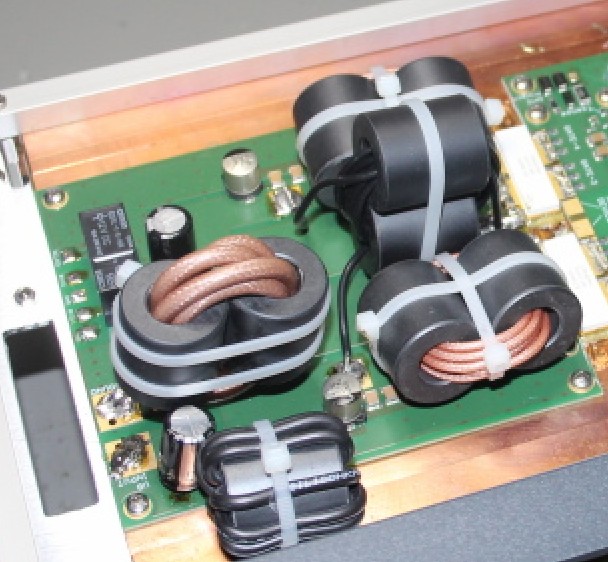
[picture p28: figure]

One or two LDMOS Transistors:

the PCB is prepared for both versions, one or two LDMOS transistors.

two LDMOS transistors generate only a little more power compared to one transistor since the output power is mainly defined by the transformers. But with two LDMOS transistors the amp is more rugged and the IM3 is a bit better. One transistor works up to 850 watts and two up to 1100 watts.

Mounting one LDMOS:

mount it in the middle of the board:

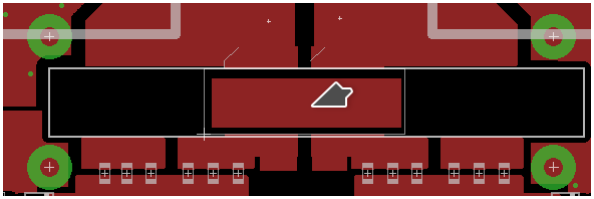
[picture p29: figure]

Mounting two LDMOS:

each LDMOS has two transistors in one case. These two transistors are connected in parallel. The drains are connected directly and the gates via decoupling resistors:

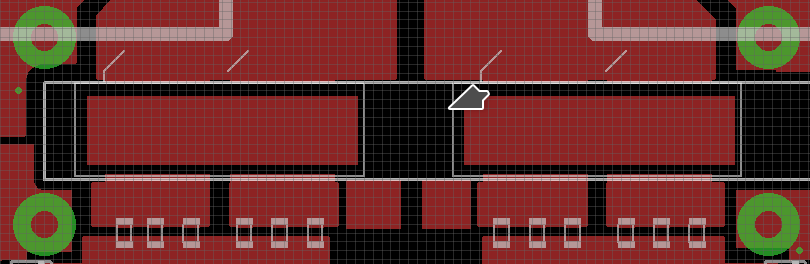
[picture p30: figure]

Coolng:

a heat spreader (copper plate, 10mm or more thick) is mandatory and the LDMOS must be soldered to this heat spreader, do NOT try to screw the LDMOS to the copper plate, it must be soldered !

There are many videos on YouTube showing how to solder it, the cooking hob works well (at least if your wife is not at home).

The PCB is mounted directly to the copper plate. Make this plate as big as possible but take care that the through-hole parts do not touch the copper.

Example: copper plate 134x103mm

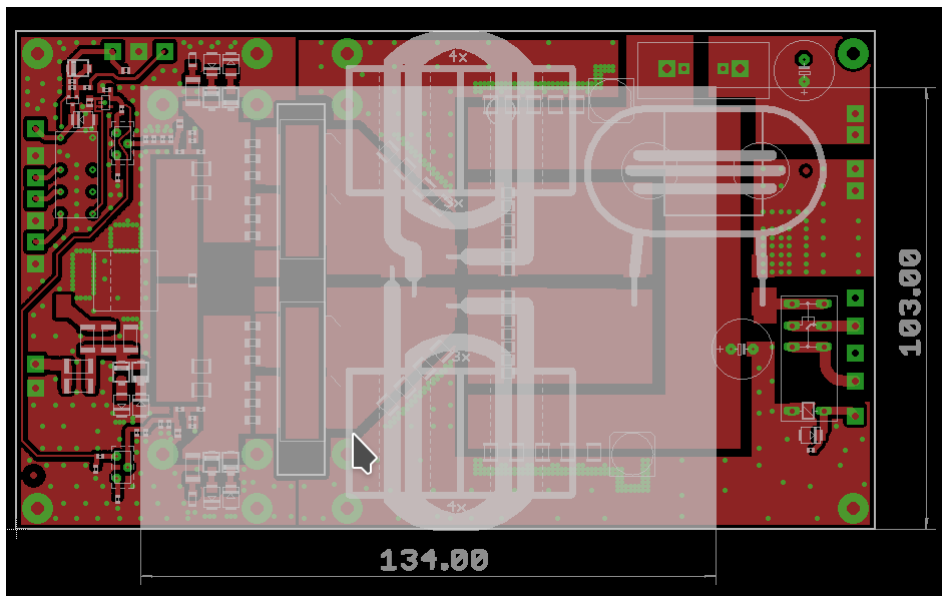
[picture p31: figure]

Two holes are labels „Tsense“. The NTCs for temperature stabilization are located near these holes. Use these holes to screw the PCB to the copper and the NTC get a good thermal contact to the cooler.

There are many other ways to manufacture the heat spreader depending which tools you have in your workshop. The bottom side should be milled or polished to have best thermal contact to an aluminium cooler.

An interesting option is to use water cooling (i.e. with parts from PC coolers) which works very well.

Push the PCBs between the pins of the LDMOS and the copper board then first fasten the screws and finally solder the LDMOS to the PCB.

Completion and options:

The board is now complete so we can do some important details:

Input Attenuator:

auf der Platine befindet sich bereits ein Eingangs-Dämpfungsglied aus R1/R2/R3/R19/R20 welches zusätzlich Schutzdioden hat.
In vielen Fällen reicht das aber noch nicht um die Empfindlichkeit der PA auf eine normales Maß zu drücken. In aller Regel wird man dem Eingang noch ein weiteres 10dB Dämpfungsglied vorschalten wollen. Damit erreicht die PA dann Vollaussteuerung bei ca. 10 Watt Eingangsleistung.

Da sich ein 10dB Eingangs-Dämpfungsglied natürlich erwärmt wird es extern aufgebaut. Die Platine hat die dazu passenden Anschlüsse:

An RF_IN schließt man den Transceiver an.
Am Anschluss TO_ATT kommt die HF (beim Senden) wieder heraus, von hier geht man also zum externen Dämpfungsglied.
Der Ausgang des externen Dämpfungsglieds geht dann an Anschluss FROM_ATT.

Schaltungsvorschlag für das Dämpfungsglied mit 2 Watt Kohleschichtwiderständen:

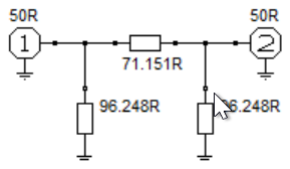
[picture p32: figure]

da es hier nur auf eine ungefähre Dämpfung ankommt, werden die idealen Werte angepasst. Statt 96,248 Ohm nimmt man 100 Ohm Widerstände und statt 71,151 Ohm nimmt man 68 Ohm (oder 2 in Reihe geschaltete 33 Ohm) Widerstände.

Normale 2W Kohleschichtwiderstände sind gut, aber es gibt auch hochwertige HF-Metallfilmwiderstände, was aber kaum Vorteile bringt.

Beim Betrieb der PA wird man merken, dass die Empfindlichkeit auf 10m und vor allem 6m deutlich abnimmt. Um eine einigermaßen gleichmäßige Empfindlichkeit zu haben kann man in diesem Dämpfungsglied die höheren Bänder anheben:

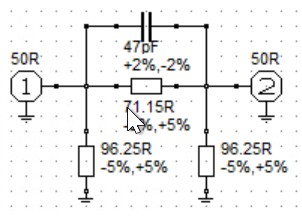
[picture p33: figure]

den genauen Wert des Kondensators muss man an der fertigen PA ermitteln.

RX-Bypass:

Damit der Transceiver im Empfangsbetrieb mit der Antenne verbunden ist muss noch eine Koax-Kabelverbindung hergestellt werden und zwar zwischen Anschluss RX_BYP1 (Eingangsteil) und RXBYP-2 (Ausgangsteil).

Relaisleitung:

Auf der Platine befinden sich zwei Pins „Relais“. Diese einfach mit einem Stück Draht verbinden.

Stromversorgung:

Die Platine benötigt zwei Spannungen:

12V (13,8V) … für die Relais und die Vorspannungserzeugung. Man kann hier die 12V des üblichen Stationsnetzteils benutzen.

50V (30 bis 50V) … für die Leistungsendstufe. Hierfür gibt es Netzgeräte von Meanwell (Reichelt) oder die bekannten HP-Servernetzteile (ebay).

Inbetriebnahme:

Ist die Kühlung aufgebaut und die Platine verdrahtet beginnt die Inbetriebnahme.
Um den teuren LDMOS Transistor zu schützen ist das ein mehrstufiger Prozess:
1. die 250 Ohm Potis so drehen, dass der Schleifer so nah wie möglich an Masse liegt, also die geringste Spannung aus dem Poti herauskommt. Dadurch ist der Ruhestrom der Transistoren Null.
2. Ausreichend große 50 Ohm Dummyload an den Ausgang anschließen.
3. Transceiver an den Eingang anschließen, 40m Band, FM und kleinst mögliche Leistung einstellen, noch nicht senden.
4. 12V anschließen

5. Anschluss „PTT“ (gleich neben dem 12V Anschluss) mit einem Stück Draht mit GND verbinden, die Relais ziehen jetzt an.
6. noch KEINE 50V anschließen, wir gehen erstmal sehr langsam vor: zunächst versorgen wir die PA aus einem kleinen Labornetzteil mit ca. 20 bis 30V und einer Strombegrenzung von ca. 3 bis 5A.
7. Ruhestrom einstellen. Es wird kein Strom fließen, da die Potis auf 0 gedreht sind. Fließt trotzdem ein Strom, so stimmt etwas nicht und man muss den Fehler suchen.
Jetzt stellen wir einen Ruhestrom von 0,5A pro Hälfte ein. Also ein Poti auf 500mA aufdrehen und danach mit dem zweiten Poti auf 1A drehen.
8. Wir entfernen die PTT Leitung von der Masse und verbinden sie jetzt mit dem PTT Ausgang des Funkgeräts.
9. An den Ausgang, parallel zur Dummyload, ein Oszilloskop anschließen um die Ausgangsleistung abschätzen zu können. (Ausgangsleistung P = Ueff² / 50)
10. Jetzt mit dem Transceiver mit minimaler Leistung (!!! Ausgangsleistung auf Minimum drehen !!! nur zu leicht übersieht man das !!!) auf ca. 7MHz senden. An der Dummyload muss eine Ausgangsleistung zu sehen sein. Das 3A Netzgerät geht möglicherweise schon in die Strombegrenzung und regelt die Spannung herunter, was aber kein Problem ist. Es kommt nur darauf an, dass wir ein wenig Ausgangsleistung sehen können. Mehr als 10 oder 20 Watt werden kaum herauskommen.
11. Ist der Test mit der 3 oder 5A Strombegrenzung erfolgreich verlaufen und es war eine Ausgangsleistung zu sehen, dann kommt jetzt Schritt 2: der Anschluss eines 50V Netzteils über einen Vorwiderstand. Man nimmt also das kräftige 50V Netzgerät (24 bis 30V würden für diesen Test auch reichen) und fügt in die Plus-Leitung einen Leistungswiderstand von ca. 3,9 Ohm ein. Der Widerstand sollte mindestens 10 Watt aushalten, aber egal, er wird bei diesen Tests vermutlich sowieso sehr heiß werden und evt kaputt gehen. Der Widerstand ist nur eine Sicherheitsmaßnahme für den Fall dass die PA einen Kurzschluss macht. Bei 50V und 3,9 Ohm kann maximal 12A fließen was dem LDMOS Transistor noch nichts anhaben kann.
Wenn man mit dem Transceiver jetzt sendet, sollte schon einen gute Ausgangsleistung von über 50 Watt zu sehen sein. Bitte nur kurz Senden, sonst raucht der 3,9 Ohm Schutzwiderstand.
12. Ist obiger Test erfolgreich verlaufen, so ist die PA vermutlich in Ordnung und kann jetzt ohne Vorwiderstand versorgt werden um die volle Leistung abzugeben.

Ab hier ist es erforderlich ein passendes Tiefpassfilter zwischen PA und Antenne anzuschließen !

Ruhestrom:

bei obiger Inbetriebnahme haben wir den Ruhestrom auf 0,5A pro Hälfte eingestellt. Wenn alles gut läuft können wir ihn erhöhen auf 2A pro Hälfte, dadurch wird die Linearität besser.
Der Ruhestrom fließt übrigens nur beim Senden, im Empfangsbetrieb ist die Vorspannung ausgeschaltet.

Für OMs die über einen Spektrumanalyser verfügen:

Man schaut sich das Spektrum am Ausgang der PA an, vor allem die erste Oberwelle, also die doppelte Sendefrequenz. Wenn man jetzt an einem der Vorspannungs-Potis ein wenig dreht, so kann man sehen wie diese erste Oberwelle größer oder kleiner wird. Durch entsprechende Einstellung kann man sie fast komplett entfernen.
Bitte „vorsichtig“ nur wenig drehen und den Ruhestrom nicht ins unendliche hochjagen, das könnte den LDMOS überlasten !

Sicherheitsmaßnahmen:

Eine Stromversorgung von 50 Volt und über 30A ist ein kräftiges Teil und im Fehlerfall gefährlich. Man muss zwei Dinge beachten:
1. Brandschutz im Fehlerfall
2. Schutz des teuren LDMOS Transistors

um diese beiden Dinge abzudecken habe ich eine einfache Schutzschaltung entwickelt. Die Schaltung befindet sich hier:
http://dj0abr.de/german/technik/kwpa/kwpa_isafe.htm

entweder man baut diese Schaltung auf oder man sorgt mit anderen Maßnahmen für eine Abschaltung im Fehlerfall.

Sicherheitshinweis zum LDMOS Transistor:

dieser ist sehr robust, aber nur am Ausgang. Am Eingang (Gate) ist er extrem empfindlich. Bei der Arbeit daher auf statische Aufladungen achten solange er noch nicht eingelötet ist.
Die Platine bitte nicht mit einer Gegenkopplung versehen, diese ist nicht notwendig und gefährdet den Transistor.
Auf geringe Steuerleistung achten. Die Platine enthält eine 2-stufige Schutzschaltung. Sendet man mit zu viel Steuerleistung, so wird als erstes die Diode am Eingangsdämpfungsglied rauchen, das ist immerhin viel billiger als der Transistor.
Ein LDMOS verträgt ein schlechtes SWR, aber nur kurz. Bei hohem SWR bitte mit einer geeigneten Schutzschaltung die PA abschalten. Abgesehen von schlechten Antennen ist der übliche Grund für ein schlechtes Ausgangs-SWR ein falsch geschaltetes Tiefpassfilter.

Diese Probleme werden vom LDMOS-PA-Controller erkannt und behandelt. Ein Aufbau dieser Zusatzplatine ist empfehlenswert.

Wie macht man einen LDMOS Transistor kaputt ?

Ich habe mal recherchiert und die üblichen Fehler von vielen OMs zusammengeschrieben. Mir selbst ist noch kein Transistor kaputt gegangen, dank der vielen Schutzmaßnahmen. Hier also die Zerstörungsliste:

- auf Schutzmaßnahmen am Eingang verzichten und irrtümlich mit 100W Steuerleistung in die PA hineinfahren.
- Eine Gegenkopplung einbauen mit dem Ziel die (sowieso gute) Linearität zu erhöhen. Überspannungen vom Ausgang (zB Antenne defekt) koppeln so aufs empfindliche Gate zurück
- Irrtümlich das falsche Tiefpassfilter gewählt. Der Transistor geht nicht sofort kaputt. Eine Schutzschaltung mit einer Reaktionszeit von ein paar 100ms reicht normal aus.
- Bei der Arbeit an der PA mit der Mess-Spitze abgerutscht und einen Kurzschluss gemacht.
- Zu schwache Dummyload brennt durch und es gibt keine Schutzschaltung für hohes SWR

- durch HF-Einstrahlung regelt das Netzteil über 50V hoch
- den Ruhestrom irrtümlich so hoch einstellen dass der LDMOS überlastet wird
- eine Kühlkörpertemperatur über 60 Grad zulassen

Anhang: Anschlusspins (wie auf der Platine beschriftet):

BYP1 | Mit BYP2 verbinden (mit RG316) | Zum Durchschleifen des Empfangssignal
RF IN | Eingang vom Transceiver
TO ATT | Ausgang zu einem ext. Dämpfungsglied | Wenn keines benutzt wird, dann direkt mit FROM_ATT verbinden
FROM ATT | Eingang von einem ext. Dämpfungsglied
+12V | Versorgung für Relais und Vorspannung | +12 bis +14V
PTT | PTT Eingang | Zum Senden auf Masse legen
RELAIS | Die beiden Pins „RELAIS“ miteinander verbinden. | Schaltleitung der Relais
RF OUT | HF Ausgang zu einem Tiefpassfilter. | Ausreichend dicke Koaxkabel benutzen. RG316 geht gerade so, RG214 ist besser.
BYP2 | Mit BYP1 verbinden (mit RG316) | Zum Durchschleifen des Empfangssignal
UB INPUT und GROUND | Anschluss für ein Netzgerät 50V min. 30A | 10mm² Kabel benutzen.

Anhang: Befestigungslöcher Maßbild:

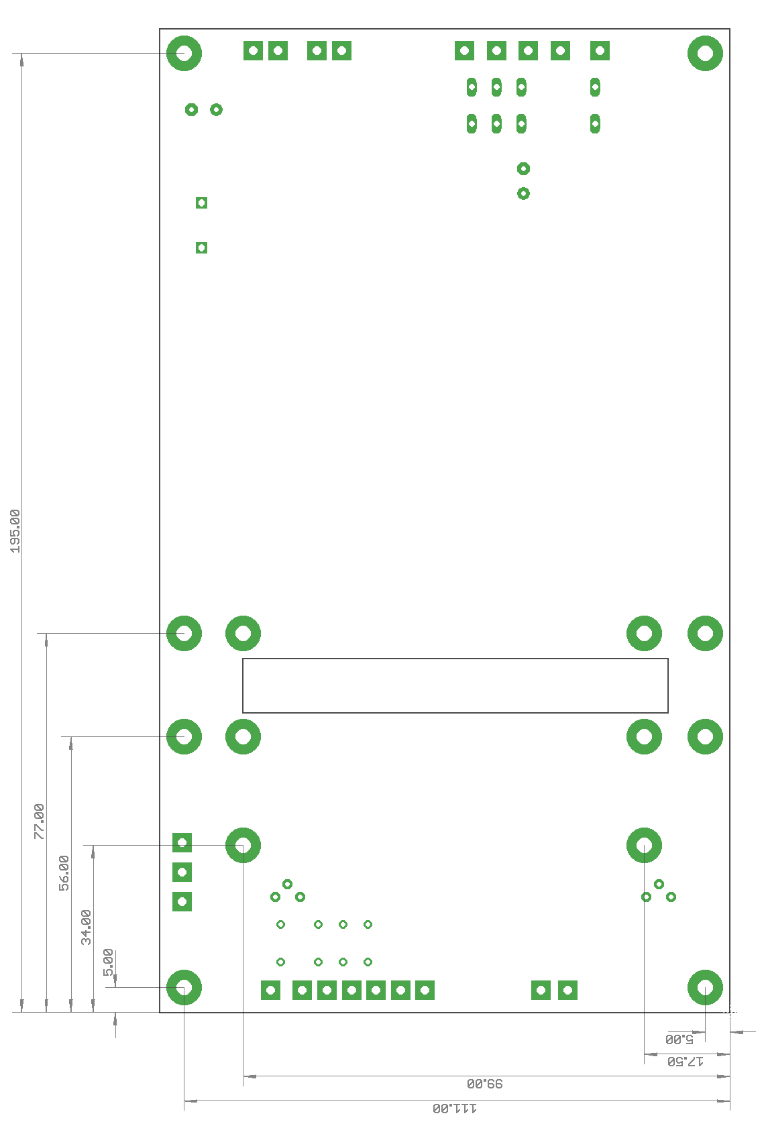
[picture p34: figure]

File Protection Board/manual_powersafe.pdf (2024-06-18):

### English language: see page 6 !

# MOSFET Hochstromschalter mit Überstromabschaltung für MOSFET/LDMOS AFU-Leistungsendstufen

Autor: Kurt Moraw, DJ0ABR
Bezugsquelle: www.helitron.de

Zur Versorgung von Leistungsendstufen werden Netzgeräte mit hohem Ausgangsstrom benutzt. Da es schwierig ist solch hohe Ströme zu schalten wird in der Regel nur die 230V Netzspannung über einen Schalter geführt und der Netzgeräteausgang dann direkt mit der Endstufe verbunden.

Dabei verlässt man sich auf die Strombegrenzung des Netzgerätes, welche in fast allen modernen Schaltnetzteilen eingebaut ist. Immer beliebter werden die 48V Servernetzteile weil sie zu extrem günstigen Preisen erhältlich sind und trotzdem Markenqualität (z.B. HP) haben.

Diese Servernetzteile lassen sich einfach auf 50V umstellen. Allerdings können sie Ströme bis 50 oder 60A liefern. Im Fehlerfall schalten sie also erst ab, wenn z.B. mehr als 60A fließen. Das klappt jedoch nur, wenn die Verdrahtung niederohmig ausgeführt wurde und wenn der Fehler (Kurzschluss) ebenfalls niederohmig ist. Andernfalls fließt eine sehr hoher Strom von vielleicht 40 oder 50A, das Netzteil schaltet nicht ab, und die Platine und Verdrahtung beginnen zu schmelzen.

Der zweite Grund für die Entwicklung dieser Platine waren die hohen Kosten der LDMOS Transistoren von um die 200.- €. Beim Bau einer PA passieren immer irgendwelche Fehler, daher sollte man eine Schutzschaltung haben welche diese Transistoren so gut wie möglich schützt.

Das dritte Problem bei der Versorgung einer Endstufe sind die Elektrolytkondensatoren auf der Endstufenplatine. Legt man eine kräftige Spannungsversorgung an, so laden sich diese Elkos schlagartig auf, es fließt der Kurzschlussstrom. Viele Netzteile erkennen das als Kurzschluss und schalten sich ab.

Dieser MOSFET Hochstromschalter kümmert sich um diese drei Punkte:

1) Ein-/Ausschalten hoher Ströme
2) Abschaltung bei erreichen eines einstellbaren Maximalstroms
3) Vorladung der Elkos

Hinweis !
Natürlich kann auch diese Platine keinen 100% Schutz bieten. Während der Entwicklungszeit meiner Endstufen von ca. 6 Monaten hat diese Platine jedoch einige Male abgeschaltet und mich und die Transistoren vor Schaden bewahrt. Beispiel: ein BLF188XR verträgt maximal 35A. Wenn man also die Abschaltung auf 30A einstellt, so hat man bereits einen wichtigen Punkt abgedeckt.

Hinweis !
Bei der Arbeit mit hohen Strömen besteht immer ein Risiko von Kabelbränden. Das gilt es unbedingt zu vermeiden. Die beste Methode dafür ist es die Verdrahtung, sowie alle in der Stromversorgung liegenden Teile, so dick und großzügig wie möglich auszuführen. Nur wenn die Verdrahtung niederohmig ist kann im Fehlerfall ein Kurzschlussstrom fließen der hoch genug ist um die Abschaltung im Netzgerät auszulösen !

Funktionsprinzip:

das Herzstück dieser Schaltung ist der BTS50085. Es handelt sich um einen einfachen kräftigen MOSFET der zur Schaltung hoher Ströme geeignet ist. Das besondere am BTS50085 ist, dass er außer des Mosfet-Schalters auch noch eine große Zahl von Schutzschaltungen eingebaut hat um sich selbst zu schützen. Im Datenblatt ist er mit maximal 58V und 44A angegeben und eignet sich daher besonders für 50 Volt LDMOS Endstufen. Durch seinen Haupteinsatzbereich

- 1 -in der Automobilelektronik erfüllt er einen guten Qualitätsstandard.

Dieser BTS50085 wurde ergänzt mit einer Schaltung zur Überstromabschaltung und zur Elko-Vorladung.

Die Abschaltschwelle kann mit dem Poti zwischen ca. 20 und 40A eingestellt werden. Eine Einstellung auf 30A ist meist passend, da die Endstufen dann schon die erlaubten 750W, und etwas mehr, abgeben können.

Bedienelemente:

Auf der Platine befinden sich vier Lötanschlüsse, zwei beschriftet mit ON und die anderen zwei mit OFF:

brückt man die ON Anschlüsse dann startet zunächst die Elko-Vorladung, solange muss man die Verbindung der ON Anschlüsse halten, das dauert ca. 0,5s (je nach Kapazität der Elkos). Danach schaltet der Schalter voll durch.

Brückt man die OFF Anschlüsse, so öffnet der Schalter.

An die folgenden Taster oder Schalter werden keine besonderen Anforderungen gestellt. Eine Spannungsfestigkeit von 60V und Strombelastbarkeit von 0,1A ist ausreichend.

Bedienung mit 2 Tastern:

Einen Taster verbindet man mit den beiden ON Anschlüssen, den anderen mit OFF. Die Taster montiert man an der Frontplatte und kann damit die Versorgung ein- und ausschalten. Beim Einschalten ist wichtig, dass man den Taster etwas länger drückt (z.B. 1 Sekunde) damit die Vorladung der Elkos komplett ist, sonst schaltet der Schalter nicht ein.

Hinweis für Benutzer des Helitron-PA-Controllers:
der PA-Controller wird ebenfalls mit zwei Tastern ein- bzw. ausgeschaltet.
Wenn man 2-polige Taster benutzt, dann lässt sich sowohl der Controller als auch diese Platine damit ein- und ausschalten. Es müssen dazu unbedingt 2-polige Taster benutzt werden, eine direkte Verbindung dieser Schalterplatine mit dem Controller ist wegen der hohen Spannungen unzulässig.

Bedienung mit einem Wechselschalter:

Man kann einen 2-poligen Wechselschalter benutzen. In einer Stellung ist ON gebrückt, in der anderen Stellung ist OFF

- 2 -gebrückt. Auch damit kann man ein- und ausschalten.

Im Vergleich zur Tasterbedienung gibt es einen Unterschied: Beim Taster ist ON nur verbunden solange man drückt, beim Schalter dauerhaft solange eingeschaltet ist.
Im Fall eines Überstroms wird in beiden Fällen ausgeschaltet. Wenn der Fehler (z.B. Kurzschluss) wieder behoben ist, dann wird beim Einsatz eines Wechselschalters sofort wieder eingeschaltet (falls er auf ON steht). Beim Taster nicht, da muss man neu drücken.

Bedienung mit Relais:

Wenn man das optionale Relais (Typ.: FIN 30.22.9 12V, siehe z.B. Reichelt) bestückt, hat es die gleiche Funktion wie der oben beschriebene Wechselschalter. Man kann das Relais mit einem ganz einfach Schalter bedienen.

Die beste Sicherheit vor Fehlbedienungen bietet der Einsatz von 2 Tastern, da hier das selbsttätige Wiedereinschalten nicht möglich ist.

Bedienung ohne Taster oder Schalter:

will man aus irgendwelchen Gründen die Ein-/Ausschaltfunktion nicht benutzen, so verbindet man die Lötaugen ON dauerhaft. Der Schalter ist dann immer eingeschaltet und schaltet sich nur bei einem zu hohen Laststrom aus. Wird die Ursache für diesen zu hohen Strom beseitigt, schaltet er sich sofort wieder ein.

Anschlüsse:

Verbindung zum Netzteil:

die mit IN beschriftete große Lötfläche wird mit einem ausreichend dicken Draht mit dem Pluspol des Netzteils verbunden.

Verbindung zur Endstufe:

die mit OUT beschriftete große Lötfläche wird mit einem ausreichend dicken Draht mit dem Pluspol der Endstufe verbunden.

Masseverbindung:

das mit GND beschriftete Lötauge wird mit dem Minuspol des Netzteils verbunden. Dieses Lötauge dient gleichzeitig auch dem Anschluss des OFF Tasters oder Schalters. Da hier kein hoher Strom fließt ist ein einfacher Draht ausreichend.

Anschluss bei Benutzung des optionalen Relais:

die ON und OFF Anschlüsse bleiben frei.
Man verbindet das Lötauge „+12“ mit der 12 Volt Stationsversorgung. Das Lötauge „OnOff“ verbindet man über einen Schalter mit Masse.

Erste Inbetriebnahme:

Prüfung der Ein/Aus Funktion:
Anstelle der Endstufe schließt man an die OUT-Lötfläche einen Widerstand gegen Masse an, der Wert ist unkritisch, z.B. 1 kOhm. Er dient nur als Grundbelastung zum Test des Schalters. Hier schließt man auch ein Voltmeter an.

Ist das Netzgerät aktiv, so wird das Voltmeter trotzdem noch nichts anzeigen weil dieser Hochstromschalter ausgeschaltet ist (eine sehr kleine Anzeige ist normal, weil wir keine besondere Last haben).

Jetzt brückt man die Anschlüsse ON, das Voltmeter wird die Netzteilspannung anzeigen.
Verbindet man kurz die Anschlüsse Off-GND, so wird wieder abgeschaltet.
- 3 -

Einstellung der Überstromabschaltung:

Hinweis !
Vor Auslieferung wird diese Platine geprüft und der Abschaltstrom auf ca. 30 A eingestellt.

Um den Abschaltstrom einzustellen dreht man das Poti im Uhrzeigersinn bis zum Anschlag. Damit ist die Überstromabschaltung auf den kleinst möglichen Abschaltstrom eingestellt (ca. 18 bis 20A). Jetzt nimmt man die Endstufe in Betrieb, am besten in FM (Dauerträger), erhöht langsam die Ausgangsleistung und beobachtet die Stromaufnahme. Der Schalter wird bei ca. 20A abschalten (das ist nur ein ungefährer Wert).

Benötigt die Endstufe mehr Strom, so dreht man das Poti entgegen dem Uhrzeigersinn um die Abschaltschwelle zu erhöhen.

Beispiel: meine Endstufe bringt bei ca. 28A die erlaubten 750 Watt. Ich erhöhe die Ausgangsleistung solange bis 28A fließen und drehe das Poti so, dass der Schalter noch nicht abschaltet, danach gebe ich noch eine Umdrehung zu damit die Abschaltschwelle sicher höher als 28A ist. Fertig.

FM und SSB:

obige Einstellung wurde in FM gemacht. Man wird sehr bald feststellen, dass im SSB Betrieb früher, also bei kleinerer Leistung, eine Abschaltung erfolgt. Das kommt daher, dass alle (auch moderne) Transceiver einen winzigen Überschwinger haben (auch bekannt als ALC Überschwinger) der ganz kurz eine höhere Leistung erzeugt als eingestellt ist, mit der Folge einer höheren Stromaufnahme.

Diese Platine hat daher eine leichte Abschaltverzögerung eingebaut welche die meisten dieser Überschwinger ignoriert. Trotzdem kann es notwendig sein das Poti noch eine Umdrehung entgegen des Uhrzeigersinns zu drehen um keine ungewollten Abschaltungen zu bekommen.

Wichtiger Hinweis !
Zu beachten ist dabei auch, dass normale Leistungsmessgeräte im SSB Betrieb nur ca. 30% der tatsächlichen Ausgangsleistung anzeigen. Spitzenwertmessgeräte zeigen fast 80 oder 90% der tatsächlichen Ausgangsleistung an, aber niemals 100%. Davon sollte man sich nicht täuschen lassen.
Wenn man die Leistung soweit aufdreht, dass das Instrument 750 Watt in SSB anzeigt, so hat man tatsächlich schon wesentlich mehr Spitzenleistung und entsprechende Stromaufnahme welche dann natürlich zu einer Abschaltung führt was auch gut so ist.

Will man die tatsächlich erreichte Spitzenleistung messen, so benötigt man eine 50 Ohm Dummyload und ein Oszilloskop welches man parallel zur Dummyload anschließt. Am Oszilloskop kann man kurze Leistungsspitzen erkennen. Am einfachsten ist das Ablesen der Spitze-Spitze Spannung Uss. Die Leistung errechnet sich mit der Formel: P = Uss² / 400

- 4 -

Betriebsbedingungen:
Das Produkt darf nur unter Einhaltung der technischen Daten betrieben werden, alle anderen, hier nicht beschriebenen, Anwendungen sind nicht zulässig.

Das Produkt ist ausschließlich für den Betrieb durch lizensierte Funkamateure zugelassen, da nur diese die notwendigen Kenntnisse zu Aufbau und Betrieb haben. Jegliche kommerzielle Anwendung oder Benutzung durch andere Personen ist ausdrücklich untersagt !

Beschädigte oder feuchte Geräte dürfen nicht in Betrieb genommen werden. Defekte oder abnormal erscheinende Geräte dürfen nicht verwendet werden. Ein Betrieb in Fahrzeugen, Luftfahrzeugen oder unter gefährlichen Bedingungen ist nicht zulässig. Aufbau, Installation, Betrieb und Verwendung dieses Produkts kann nicht überwacht werden. Daher liegt die volle Verantwortung im Umgang mit dem Produkt beim Betreiber. Das Produkt darf nur in Betrieb genommen werden, wenn sich der Anwender über Risiken und Gefahren die aus dem Betrieb resultieren können im Klaren ist. Der Hersteller übernimmt keinerlei Haftung für Personenschäden, Sachschäden, Verluste oder Kosten, die sich aus fehlerhafter Verwendung oder Betrieb dieses Produkts ergeben oder in irgendeiner Weise damit zusammenhängen. Das gilt insbesondere für Schadensersatzansprüche, die durch Ausfall oder Fehlfunktion ausgelöst wurden. Sollte der Anwender nicht die notwendigen Kenntnisse zum Aufbau, zur Installation oder zur Inbetriebnahme haben oder sollte er mit diesen Betriebsbedingungen nicht einverstanden sein, darf das Produkt nicht benutzt werden. Es gelten die gesetzlichen Gewährleistungsfristen. Alle weitergehenden Ansprüche sind ausgeschlossen.

### WEEE-Reg.-Nr.:DE75652825

- 5 -

# MOSFET high current switch with overcurrent shutdown for MOSFET / LDMOS HAM-RADIO power amplifiers

### Author: Kurt Moraw, DJ0ABR Supplier: www.helitron.de

Power supplies with high output current are used to supply power amplifiers. Since it is difficult to switch such high currents, usually only the 230V mains voltage is passed through a switch and the power supply output is then connected directly to the amplifier.

It relies on the current limit of the power supply, which is installed in almost all modern switching power supplies. The 48V server power supplies are becoming increasingly popular because they are available at extremely low prices and still have brand quality (e.g., HP).

These server power supplies can easily be switched to 50V. However, they can deliver currents up to 50 or 60A. In the event of a fault, they therefore only switch off if the current is more than 60A. However, this only works if the wiring has been carried out with low resistance and if the fault (short circuit) is also low-resistance. Otherwise, a very high current of perhaps 40 or 50A will flow, the power supply will not turn off, and the board and wiring will start to melt.

The second reason for the development of this board was the high cost of the LDMOS transistors of about $200.- . When building a PA, there are always some errors, so you should have a protection circuit that protects these transistors and of course yourself.

The third problem in the supply of an amplifier are the electrolytic capacitors on the power amplifier board. If you apply a strong power supply, then these electrolytic capacitors charge up suddenly, the short-circuit current flows. Many power supplies detect this as a short circuit and turn off immediately.

This MOSFET high current switch takes care of these three issues:

1) Switch on / off high currents
2) Shutdown when reaching an adjustable maximum current
3) slow precharge the electrolytic capacitors

Note !
Of course, this board can not provide 100% protection. However, during the development time of my power amplifiers of about 6 months, this board has shut down several times and kept me and the transistors from harm. Example: a BLF188XR can tolerate a maximum of 35A. So if you set the shutdown to 30A, you have already covered an important point.

Note !
When working with high currents, there is always a risk of cable fires. It is important to avoid this. The best method for doing this is to make the wiring, as well as all parts in the power supply, as thick and low-impedence as possible. Only if the wiring is low-impedance the short-circuit current flow in the event of a fault that is high enough to trigger the fuses in the power supply unit!

How it works:

the heart of this circuit is the BTS50085. It is a simple powerful MOSFET suitable for switching high currents. The special thing about the BTS50085 is that in addition to the mosfet switch, it also has a large number of protection circuits to protect itself. It is specified in the data sheet with a maximum of 58V and 44A and is therefore particularly suitable for 50 volts LDMOS power amplifiers. Due to its main application in automotive electronics it fulfills a good

- 6 -

quality standard.

This BTS50085 has been supplemented with a circuit for overcurrent switch-off and for pre-charging.

The switch-off threshold can be set with the potentiometer between approx. 20 and 40A. A setting on 30A is usually suitable.

Connections:

There are four solder terminals on the board, two labeled with ON and the other two with OFF:

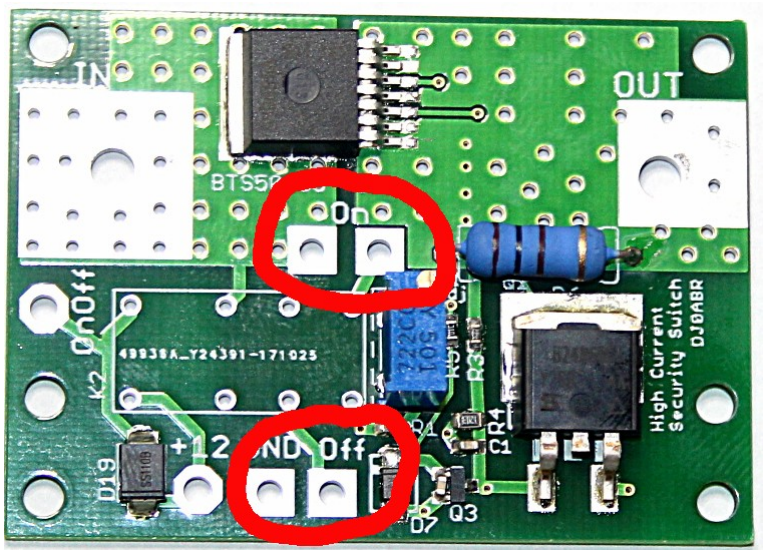
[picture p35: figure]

If you bridge the ON terminals then the electrolytic capacitors precharge starts, you must hold the connection of the ON terminals for approx. 0.5s (depending on capacity of the electrolytic capacitors). After that, the switch will be turned on.

If you close the OFF terminals, the switch opens.

There are no special requirements for the following buttons or switches. 60V and 0.1A buttons or switches are sufficient.

Operation with 2 buttons:

One button is connected to the two ON terminals, the other to the OFF terminals. The buttons are mounted on the front panel and can thus switch the supply on and off. When switching on, it is important that you press the button a little longer (for example, 1 second) so that the pre-charging of the capacitors is complete, otherwise the switch does not turn on.

Note for users of the Helitron PA controller:
the PA controller is also switched on or off with two buttons.
If you use buttons with two switches inside, then both the controller and this board can be switched on and off. It is absolutely necessary to use 2-pole pushbutton, a direct connection of this switchboard to the controller is not allowed because of the high voltages.
- 7 -

Operation with a changeover switch:

You can use a 2-pole changeover switch. In one position, ON is bridged, in the other position OFF is bridged.

There is a difference in comparison with the pushbutton operation: with the pushbutton ON is only connected as long as it is pressed, while with the switch it is permanently switched on.
In the case of an overcurrent it turns off in both cases. If the fault (for example, short circuit) is corrected again, then a changeover switch is immediately switched on again (if it is set to ON). While the push button is not, you have to press it again.

Operation with a relay:

If you equip the optional relay (type .: Finder 30.22.9 12V or similar), it has the same function as the changeover switch described above. You can operate the relay with a simple switch.

The best safety against incorrect operation is provided by the use of 2 buttons, since automatic restarting is not possible here.

Operation without button or switch:

if you do not want to use the on / off function for any reason, you connect the pads ON permanently. The switch is then always switched on and only switches off when the load current is too high. If the cause for this too high current is eliminated, it will switch on again immediately.

Connections:

Connection to the power supply:

the large solder pad labeled IN is connected to the positive pole of the power supply unit with a sufficiently thick wire.

Connection to the power amplifier:

The large soldering pad labeled OUT is connected to the plus pole of the power amplifier with a sufficiently thick wire.

Ground connection:

the GND-labeled pad is connected to the negative terminal of the power supply. This pad also is used to connect the OFF button or switch. Since no high current flows here, a simple wire is sufficient.

Connection when using the optional relay:

the ON and OFF connections remain free.
Connect the pad "+12" to the 12 Volt station supply. The pad "OnOff" is connected via a switch to ground.

First commissioning:

Checking the on / off function:
Instead of the power amplifier, connect the OUT pad via a resistor to ground, the value is not critical, e.g. 1 kOhm. It serves only as a basic load for testing the switch. Connect a voltmeter in parallel to this resistor.

If the power supply is active, the voltmeter will still not show anything because this high current switch is off (a very small display is normal because we have no special load).

Now you bridge the connections ON, the voltmeter will display the power supply voltage.
If you connect the pins Off-GND, it will be switched off again.
- 8 -

Setting the overcurrent cutoff:

Note !
Before delivery, this board is tested and the shutdown current is set to approx. 30 A.

To set the cut-off current, turn the potentiometer fully clockwise. This sets the overcurrent switch-off to the smallest possible switch-off current (approximately 18 to 20A). Now you put the power amplifier into operation, preferably in FM (continuous carrier), slowly increase the output power and monitors the power consumption. The switch will turn off at about 20A (that's just an approximate value).

If the power amplifier requires more current, turn the potentiometer counterclockwise to increase the switch-off threshold.

Example: my power amplifier generates 750 watts at approx. 28A. I increase the output power up to a load current of 28A and turn the potentiometer clockwise until the switch turns off, then I give one more turn so that the switch-off threshold is certainly higher than 28A. Finished.

FM and SSB:

above adjustment was done in FM mode (continous carrier). You will notice that in SSB operation the shutdown occurs at a lower output power. This is because all (even modern) transceivers have a tiny overshoot (also known as ALC overshoot) that generates a higher power, resulting in a higher power consumption.

Therefore this board has a slight turn off delay which ignores most of these overshoots. Nevertheless, it may be necessary to turn the potentiometer one more turns clockwise to avoid unwanted shutdowns.

Important NOTE !
It should also be noted that normal power meters in SSB mode show only about 30% of the actual output power. Peak meters indicate nearly 80 or 90% of the actual output, but never 100%. You should not be fooled by that.
If you increase the power output to i.e. 750 watts SSB on the instrument, then you have actually much more peak power and corresponding current consumption which of course leads to a shutdown which is good.

If you want to measure the real peak power, you need a 50 ohms dummy load and an oscilloscope which you connect in parallel with the dummy load. The oscilloscope can detect short power peaks. The easiest way is to read the peak-to-peak voltage Upp. The power is calculated using the formula: P = Upp² / 400

- 9 -

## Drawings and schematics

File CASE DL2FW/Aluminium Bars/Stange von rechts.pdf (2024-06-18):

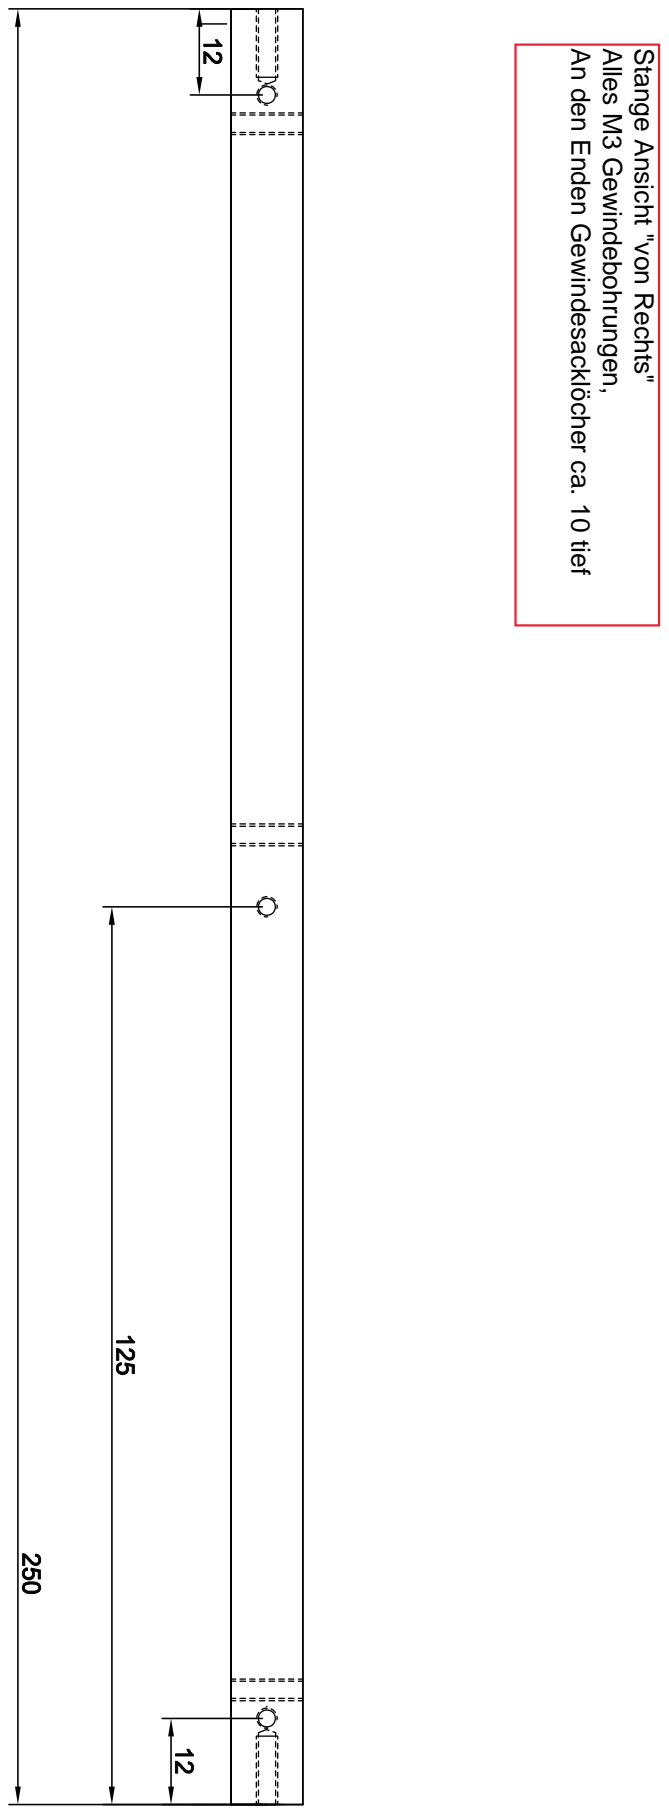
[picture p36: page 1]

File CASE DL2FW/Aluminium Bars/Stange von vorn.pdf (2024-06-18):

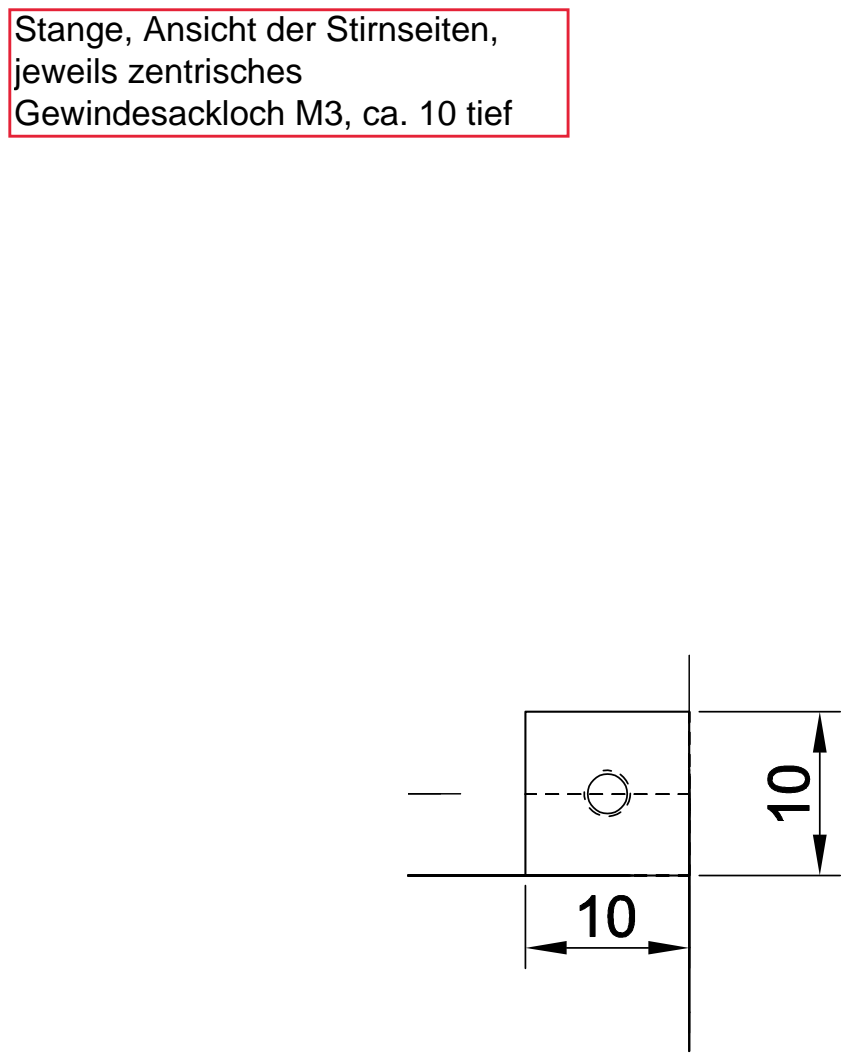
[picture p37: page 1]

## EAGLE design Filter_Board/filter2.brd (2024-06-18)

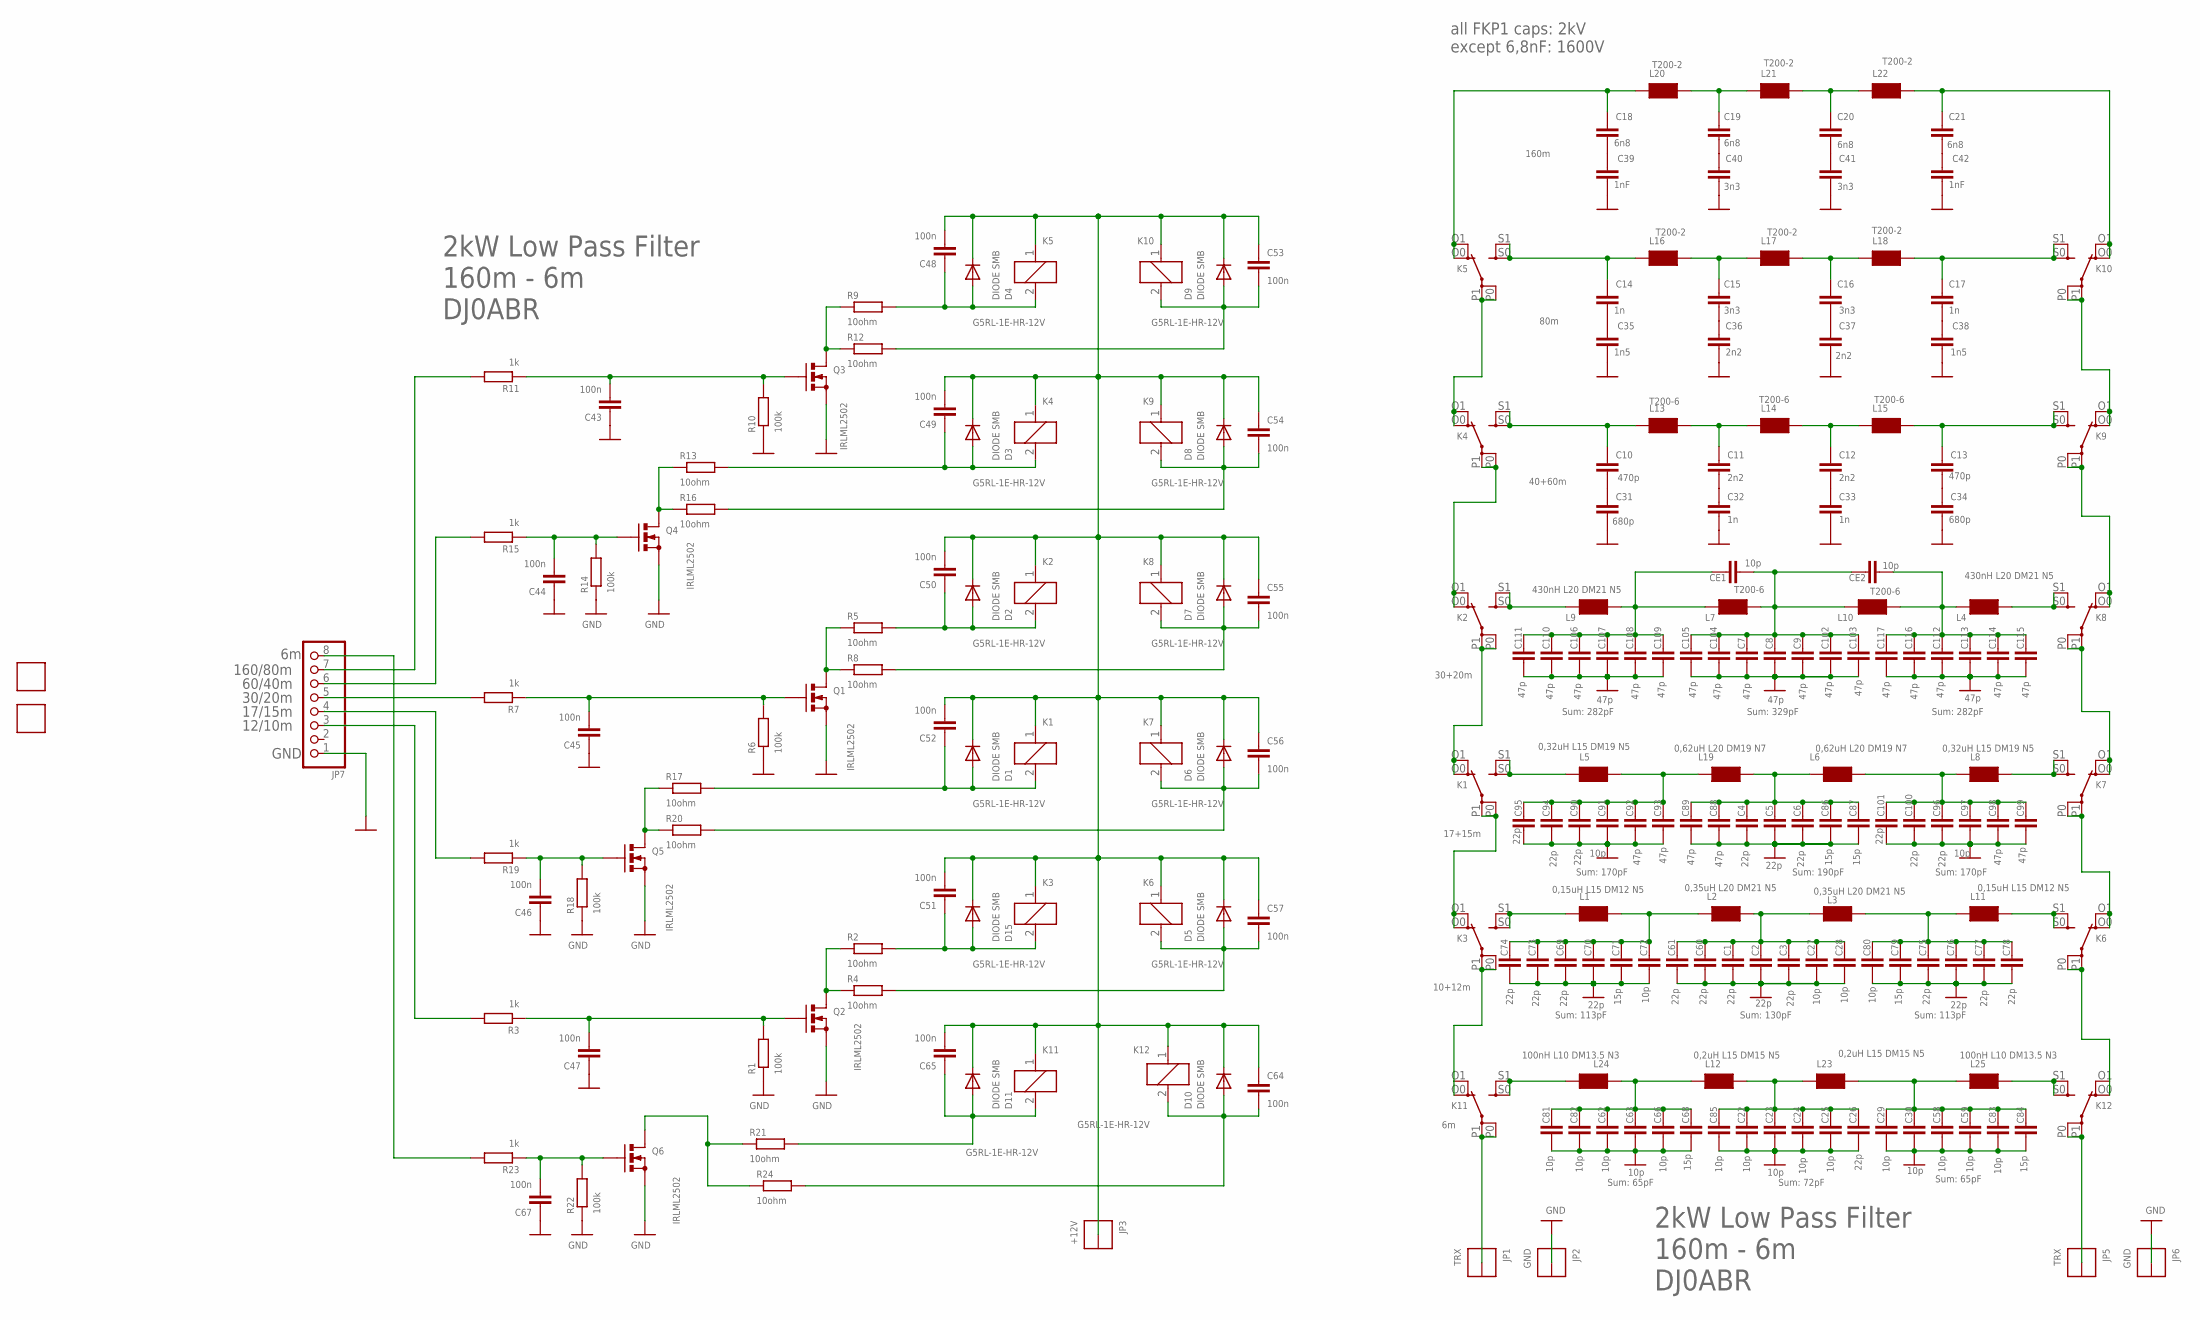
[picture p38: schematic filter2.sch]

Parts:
C1, C2, C3, C4, C5, C6, C26, C60, C61, C69, C70, C73, C74, C75, C76, C77, C78, C90, C94, C95, C96, C100, C101: 22p; C1812K
C7, C8, C9, C88, C89, C92, C93, C98, C99, C102, C103, C104, C105, C106, C107, C108, C109, C110, C111, C112, C113, C114, C115, C116, C117: 47p; C1812K
C10, C13: 470p; C150-064X183
C11, C12, C36, C37: 2n2; C225-074X268
C14, C17, C32, C33: 1n; C225-062X268
C15, C16: 3n3; C225-074X268
C18, C19, C20, C21: 6n8; C225-074X268
C22, C23, C24, C25, C27, C28, C29, C30, C58, C59, C62, C63, C66, C72, C80, C81, C82, C83, C85, C91, C97: 10p; C1812K
C31, C34: 680p; C150-064X183
C35, C38: 1n5; C225-074X268
C39, C42: 1nF; C225-074X268
C40, C41: 3n3; C225-087X268
C43, C44, C45, C46, C47, C48, C49, C50, C51, C52, C53, C54, C55, C56, C57, C64, C65, C67: 100n; C0603K
C68, C71, C79, C84, C86, C87: 15p; C1812K
CE1, CE2: 10p; C1812K
D1, D2, D3, D4, D5, D6, D7, D8, D9, D10, D11, D15: DIODE SMB; SMB
FID1, FID2: FIDUCIAL
JP1, JP5: TRX; THICKPIN
JP2, JP6: GND; THICKPIN
JP3: +12V; THICKPIN
JP7: PINHD-1X8; 1X08
K1, K2, K3, K4, K5, K6, K7, K8, K9, K10, K11, K12: G5RL-1E-HR-12V; G2RE
L1, L11: 0,15uH L15 DM12 N5; LUFTSPULE_L15XDM14
L2, L3: 0,35uH L20 DM21 N5; LUFTSPULE_L17XDM20
L4, L9: 430nH L20 DM21 N5; LUFTSPULE_20X20RM20
L5, L8: 0,32uH L15 DM19 N5; LUFTSPULR_L15XDM20
L6, L19: 0,62uH L20 DM19 N7; LUFTSPULE_20X20RM20
L7, L10, L13, L14, L15: T200-6; KERN200_STEHEND_2PIN
L12, L23: 0,2uH L15 DM15 N5; LUFTSPULE_L15XDM14
L16, L17, L18, L20, L21, L22: T200-2; KERN200_STEHEND_2PIN
L24, L25: 100nH L10 DM13.5 N3; LUFTSPULE_10X13K5
Q1, Q2, Q3, Q4, Q5, Q6: IRLML2502; SOT23
R1, R6, R10, R14, R18, R22: 100k; R0603
R2, R4, R5, R8, R9, R12, R13, R16, R17, R20, R21, R24: 10ohm; R0603
R3, R7, R11, R15, R19, R23: 1k; R0603

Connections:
+12V: C48.2, C49.2, C50.2, C51.2, C52.2, C53.1, C54.1, C55.1, C56.1, C57.1, C64.1, C65.2, D1.C, D2.C, D3.C, D4.C, D5.C, D6.C, D7.C, D8.C, D9.C, D10.C, D11.C, D15.C, JP3.1, K1.1, K2.1, K3.1, K4.1, K5.1, K6.1, K7.1, K8.1, K9.1, K10.1, K11.1, K12.1
GND: C1.2, C2.2, C3.2, C4.2, C5.2, C6.2, C7.2, C8.2, C9.2, C22.2, C23.2, C24.2, C25.2, C26.2, C27.2, C28.2, C29.2, C30.2, C31.2, C32.2, C33.2, C34.2, C35.2, C36.2, C37.2, C38.2, C39.2, C40.2, C41.2, C42.2, C43.1, C44.1, C45.1, C46.1, C47.1, C58.2, C59.2, C60.2, C61.2, C62.2, C63.2, C66.2, C67.1, C68.2, C69.2, C70.2, C71.2, C72.2, C73.2, C74.2, C75.2, C76.2, C77.2, C78.2, C79.2, C80.2, C81.2, C82.2, C83.2, C84.2, C85.2, C86.2, C87.2, C88.2, C89.2, C90.2, C91.2, C92.2, C93.2, C94.2, C95.2, C96.2, C97.2, C98.2, C99.2, C100.2, C101.2, C102.2, C103.2, C104.2, C105.2, C106.2, C107.2, C108.2, C109.2, C110.2, C111.2, C112.2, C113.2, C114.2, C115.2, C116.2, C117.2, JP2.1, JP6.1, JP7.1, Q1.2 (S), Q2.2 (S), Q3.2 (S), Q4.2 (S), Q5.2 (S), Q6.2 (S), R1.1, R6.1, R10.1, R14.1, R18.1, R22.1
unnamed: K6.P0, K6.P1, K12.O0 (O), K12.O1 (O)
unnamed: K3.S0 (S), K3.S1 (S), L1.P$1 (1)
unnamed: K1.P0, K1.P1, K3.O0 (O), K3.O1 (O)
unnamed: C75.1, C76.1, C77.1, C78.1, C79.1, C80.1, L3.P$2 (2), L11.P$1 (1)
unnamed: K1.S0 (S), K1.S1 (S), L5.P$1 (1)
unnamed: K1.O0 (O), K1.O1 (O), K2.P0, K2.P1
unnamed: C1.1, C2.1, C3.1, C27.1, C28.1, C60.1, C61.1, L2.P$2 (2), L3.P$1 (1)
unnamed: K2.S0 (S), K2.S1 (S), L9.P$1 (1)
unnamed: K2.O0 (O), K2.O1 (O), K4.P0, K4.P1
unnamed: K8.S0 (S), K8.S1 (S), L4.P$2 (2)
unnamed: K4.O0 (O), K4.O1 (O), K5.P0, K5.P1
unnamed: C106.1, C107.1, C108.1, C109.1, C110.1, C111.1, CE1.1, L7.1, L9.P$2 (2)
unnamed: K7.S0 (S), K7.S1 (S), L8.P$2 (2)
unnamed: Q2.3 (D), R2.1, R4.1
unnamed: K6.S0 (S), K6.S1 (S), L11.P$2 (2)
unnamed: K6.O0 (O), K6.O1 (O), K7.P0, K7.P1
unnamed: K7.O0 (O), K7.O1 (O), K8.P0, K8.P1
unnamed: K8.O0 (O), K8.O1 (O), K9.P0, K9.P1
unnamed: K9.O0 (O), K9.O1 (O), K10.P0, K10.P1
unnamed: C47.2, Q2.1 (G), R1.2, R3.1
unnamed: C90.1, C91.1, C92.1, C93.1, C94.1, C95.1, L5.P$2 (2), L19.P$1 (1)
unnamed: C4.1, C5.1, C6.1, C86.1, C87.1, C88.1, C89.1, L6.P$1 (1), L19.P$2 (2)
unnamed: C96.1, C97.1, C98.1, C99.1, C100.1, C101.1, L6.P$2 (2), L8.P$1 (1)
unnamed: C18.1, K5.O0 (O), K5.O1 (O), L20.1
unnamed: C7.1, C8.1, C9.1, C102.1, C103.1, C104.1, C105.1, CE1.2, CE2.1, L7.2, L10.1
unnamed: C112.1, C113.1, C114.1, C115.1, C116.1, C117.1, CE2.2, L4.P$1 (1), L10.2
unnamed: C10.1, K4.S0 (S), K4.S1 (S), L13.1
unnamed: C11.1, L13.2, L14.1
unnamed: C12.1, L14.2, L15.1
unnamed: C13.1, K9.S0 (S), K9.S1 (S), L15.2
unnamed: C14.1, K5.S0 (S), K5.S1 (S), L16.1
unnamed: C15.1, L16.2, L17.1
unnamed: C16.1, L17.2, L18.1
unnamed: C17.1, K10.S0 (S), K10.S1 (S), L18.2
unnamed: K3.P0, K3.P1, K11.O0 (O), K11.O1 (O)
unnamed: C19.1, L20.2, L21.1
unnamed: C20.1, L21.2, L22.1
unnamed: Q1.3 (D), R5.1, R8.1
unnamed: C45.2, Q1.1 (G), R6.2, R7.1
unnamed: Q3.3 (D), R9.1, R12.1
unnamed: C43.2, Q3.1 (G), R10.2, R11.1
unnamed: Q4.3 (D), R13.1, R16.1
unnamed: C44.2, Q4.1 (G), R14.2, R15.1
unnamed: Q5.3 (D), R17.1, R20.1
unnamed: C46.2, Q5.1 (G), R18.2, R19.1
unnamed: JP7.5, R7.2
unnamed: JP7.6, R15.2
unnamed: JP7.7, R11.2
unnamed: C22.1, C23.1, C24.1, C25.1, C26.1, C85.1, L12.P$2 (2), L23.P$1 (1)
unnamed: C21.1, K10.O0 (O), K10.O1 (O), L22.2
unnamed: C69.1, C70.1, C71.1, C72.1, C73.1, C74.1, L1.P$2 (2), L2.P$1 (1)
unnamed: C13.2, C34.1
unnamed: C21.2, C42.1
unnamed: C20.2, C41.1
unnamed: C19.2, C40.1
unnamed: C18.2, C39.1
unnamed: C10.2, C31.1
unnamed: C11.2, C32.1
unnamed: C12.2, C33.1
unnamed: C17.2, C38.1
unnamed: C16.2, C37.1
unnamed: C15.2, C36.1
unnamed: C14.2, C35.1
unnamed: JP7.4, R19.2
unnamed: JP7.3, R3.2
unnamed: JP1.1, K11.P0, K11.P1
unnamed: K11.S0 (S), K11.S1 (S), L24.P$1 (1)
unnamed: Q6.3 (D), R21.1, R24.1
unnamed: C62.1, C63.1, C66.1, C68.1, C81.1, C82.1, L12.P$1 (1), L24.P$2 (2)
unnamed: C29.1, C30.1, C58.1, C59.1, C83.1, C84.1, L23.P$2 (2), L25.P$1 (1)
unnamed: K12.S0 (S), K12.S1 (S), L25.P$2 (2)
unnamed: JP5.1, K12.P0, K12.P1
unnamed: C67.2, Q6.1 (G), R22.2, R23.1
unnamed: JP7.8, R23.2
R1: C50.1, D2.A, K2.2, R5.2
R2: C51.1, D15.A, K3.2, R2.2
R3: C52.1, D1.A, K1.2, R17.2
R4: C65.1, D11.A, K11.2, R21.2
R5: C49.1, D3.A, K4.2, R13.2
R8: C48.1, D4.A, K5.2, R9.2
RB6: C64.2, D10.A, K12.2, R24.2
RB10: C57.2, D5.A, K6.2, R4.2
RB15: C56.2, D6.A, K7.2, R20.2
RB20: C55.2, D7.A, K8.2, R8.2
RB40: C54.2, D8.A, K9.2, R16.2
RB80: C53.2, D9.A, K10.2, R12.2

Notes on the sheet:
10+12m
30+20m
40+60m
80m
160m
17+15m
160/80m
60/40m
30/20m
17/15m
12/10m
GND
2kW Low Pass Filter 160m - 6m DJ0ABR
all FKP1 caps: 2kV except 6,8nF: 1600V
Sum: 282pF
Sum: 329pF
Sum: 170pF
Sum: 190pF
Sum: 113pF
Sum: 130pF
Sum: 65pF
Sum: 72pF

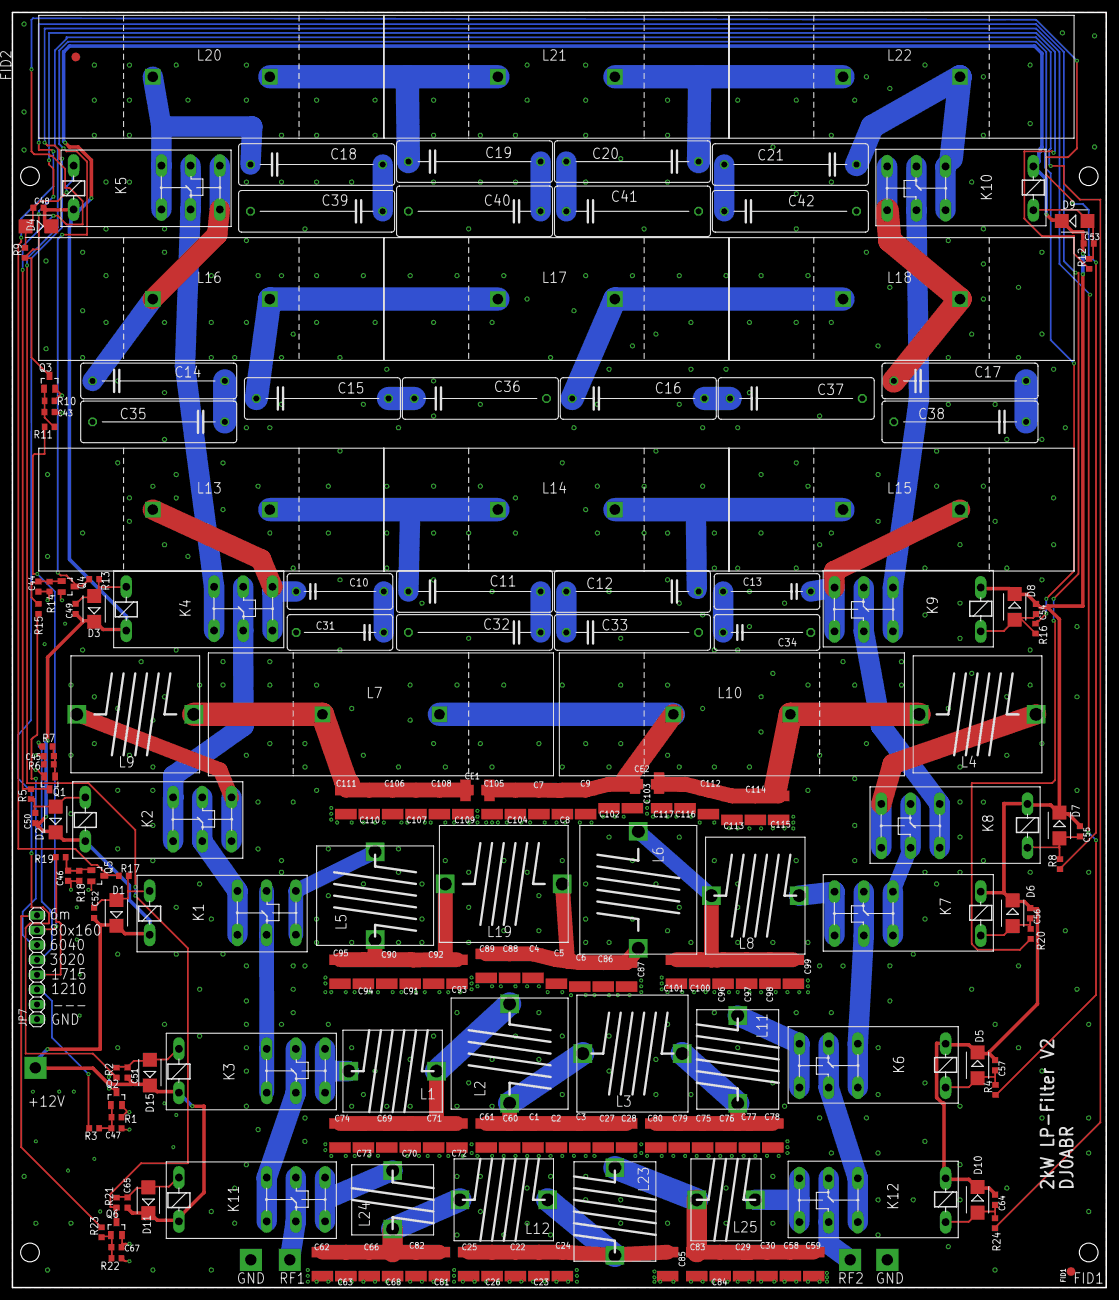
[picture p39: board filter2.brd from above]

Board: 2 copper layers, 187.0 x 218.0 mm, 206 parts (0 on the bottom side), 88 nets.

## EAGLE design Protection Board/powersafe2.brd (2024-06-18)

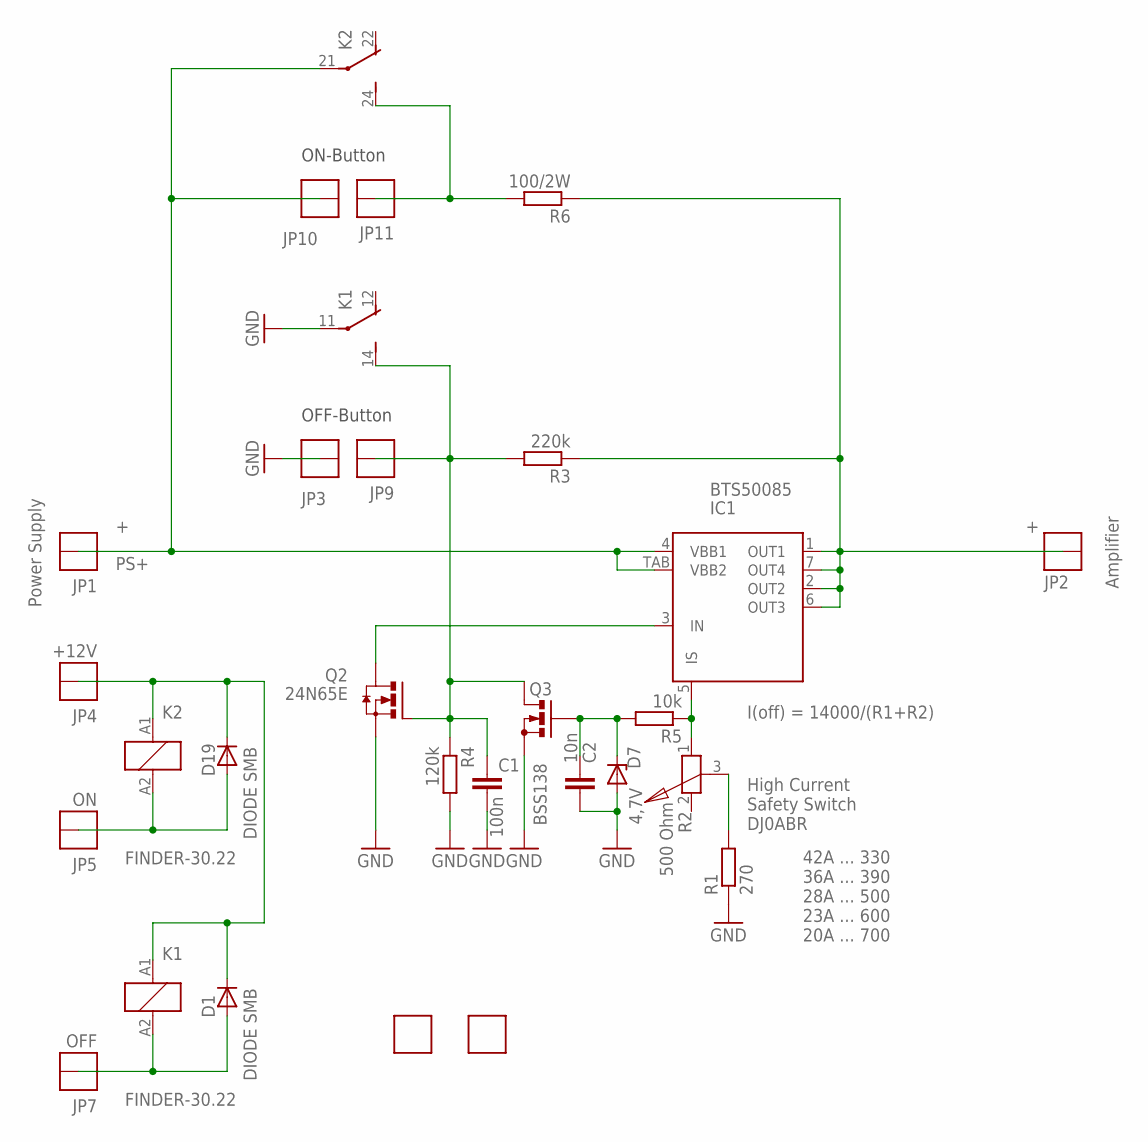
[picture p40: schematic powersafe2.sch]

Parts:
C1: 100n; C0603K
C2: 10n; C0603K
D1, D19: DIODE SMB; SMB
D7: 4,7V; SMA
FID1, FID2: FIDUCIAL
IC1: BTS50085; PG-TO220-7-4
JP1, JP2: THICKPINPIN_4QMM; PIN_4QMM
JP3, JP9, JP10, JP11: THICKPINSQUARE; THICKPIN
JP4: +12V; THICKPIN_OCT
JP5: ON; THICKPIN_OCT
JP7: OFF; THICKPIN_OCT
K1, K2: FINDER-30.22
Q2: 24N65E; D2PACK
Q3: BSS138; SOT23
R1: 270; R0603
R2: 500 Ohm; MINIPOTI
R3: 220k; R0603
R4: 120k; R0603
R5: 10k; R0603
R6: 100/2W; P0613/15

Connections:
GND: C1.2, C2.2, D7.A, JP3.1, K1.11, Q2.3 (S), Q3.2 (S), R1.1, R4.2
unnamed: C2.1, D7.C, Q3.1 (G), R5.2
unnamed: IC1.3 (IN), Q2.2 (D)
unnamed: C1.1, JP9.1, K1.14 (S), Q2.1 (G), Q3.3 (D), R3.2, R4.1
unnamed: IC1.5 (IS), R2.1, R5.1
unnamed: JP11.1, K2.24 (S), R6.2
unnamed: D19.A, JP5.1, K2.A2 (2)
unnamed: D1.C, D19.C, JP4.1, K1.A1 (1), K2.A1 (1)
unnamed: R1.2, R2.3
unnamed: D1.A, JP7.1, K1.A2 (2)
PA+: IC1.1 (OUT1), IC1.2 (OUT2), IC1.6 (OUT3), IC1.7 (OUT4), JP2.P$1, R3.1, R6.1
PS+: IC1.4 (VBB1), IC1.TAB (VBB2), JP1.P$1, JP10.1, K2.21

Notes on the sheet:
I(off) = 14000/(R1+R2)
High Current Safety Switch DJ0ABR
42A ... 330 36A ... 390 28A ... 500 23A ... 600 20A ... 700
OFF-Button
ON-Button
Amplifier
Power Supply

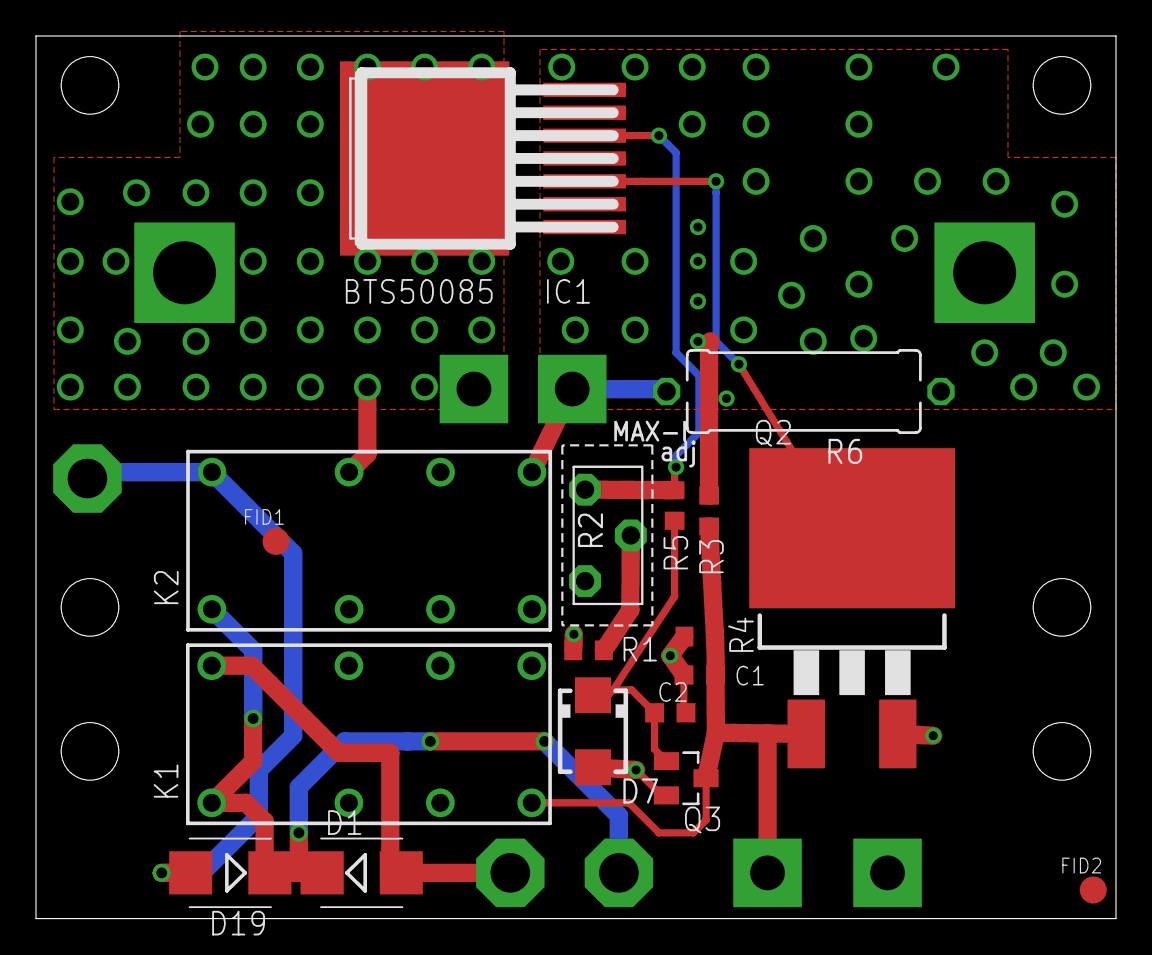
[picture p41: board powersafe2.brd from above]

Board: 2 copper layers, 60.0 x 49.0 mm, 27 parts (0 on the bottom side), 12 nets.

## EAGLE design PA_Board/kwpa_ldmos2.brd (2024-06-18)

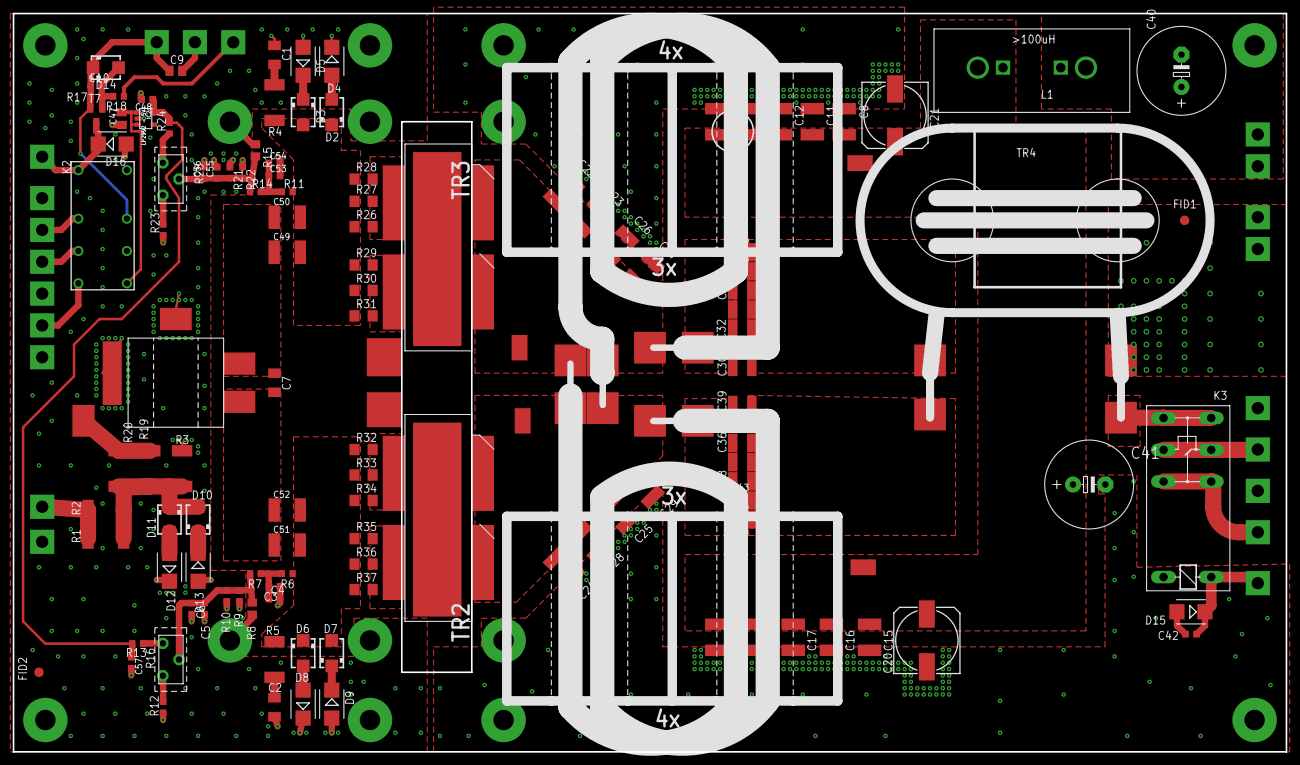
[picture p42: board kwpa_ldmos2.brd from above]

Board: 2 copper layers, 200.0 x 116.0 mm, 161 parts (0 on the bottom side), 49 nets.

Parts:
C1, C2: 10n/450V; C1206K
C3, C5, C53, C55, C57: 1u; C0603K
C4, C42, C54: 100n; C0603K
C6, C10, C56: 10n; C0603K
C7: opt.; C1206K
C8, C11, C15, C16: 10n; C1812K
C9: 10u/25; C0805K
C12, C13, C17, C18, C49, C50, C51, C52: 100n; C1812K
C14, C19: 1u; C1812K
C20, C21: 100u/63; 153CLV-1014
C22, C23, C24, C25, C26, C27, C28, C29: 120p; C1812K
C30, C31, C32, C33, C34, C35, C36, C37, C38, C39, C43, C44, C45, C46: 10n; C1210K
C40, C41: 470uF/63V; E5-13
C47: 10u; C0805K
C48: 10u; C0603K
D2, D6: 8,2V; SMA
D3, D7: 4,7V; SMA
D4, D5, D8, D9, D12, D13, D15, D16: DIODE SMB; SMB
D10, D11: SMBJ15A; SMA
D14: 6,2V/1W; SMA
FID1, FID2: FIDUCIAL
H1, H2, H3, H4, H5, H6, H7, H8, H9, H10, H11, H12, H13, H14: HOLE_32; HOLE32
IC2: LP2992 - 5V; SOT23-5
JP1: RF_IN; THICKPIN
JP2, JP3, JP8, JP10, JP12, JP14, JP15, JP20, JP22: GND; THICKPIN
JP4: RXBYP-2; THICKPIN
JP5: +12..+14V; THICKPIN
JP7: RX_BYP1; THICKPIN
JP9: PTT; THICKPIN
JP11: RF-OUT; THICKPIN
JP13, JP16: +50V; THICKPIN
JP17, JP18: RELAIS; THICKPIN
JP19: TO_ATT; THICKPIN
JP21: FROM_ATT; THICKPIN
K2: FINDER-30.22
K3: G5RL-1E-HR-12V; G2RE
L1: >100uH; KERN90_STEHEND_2PIN
R1, R2, R19, R20: 22/2W; R2512
R3: 100/2W; R2512
R4, R5: 10/2W; R2512
R6, R11: 1k; R0603
R7, R14: 470; R0603
R8, R15: NTC0805J5K0; R0805
R9, R21: 560; R0603
R10, R22: 5k6; R0603
R12, R23: 47; R0603
R13, R24: 270; R0603
R16, R25: 250; MINIPOTI
R17, R18: 10k; R0603
R26, R27, R28, R29, R30, R31, R32, R33, R34, R35, R36, R37: 10; R1206
T1, T2: BLF188
T1P3, T1P4, T1S3, T1S4: SMDPAD2,5X4
T7: IRLML6401; SOT23
TR1: 4:1 Laird 28B0562-100; KW-INPUT_LAIRD_28B0562-100
TR2: DOPPELRINGKERN
TR3: DOPPELRINGKERN_REV
TR4: DOPPELLMANTEL_STEHEND

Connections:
ATTM: D10.A, D11.C, R1.2, R2.2, R3.2, R19.1, R20.1
BYP1: JP7.1, K2.12
DD1: C49.2, C50.2, D2.C, D3.A, R4.1, R11.2, R26.1, R27.1, R28.1, R29.1, R30.1, R31.1
DD2: C51.2, C52.2, D6.C, D7.A, R5.2, R6.2, R32.1, R33.1, R34.1, R35.1, R36.1, R37.1
DI1: C7.1, C49.1, C50.1, TR1.OUT2
DI2: C7.2, C51.1, C52.1, TR1.OUT1
DRAIN1: C22.2, C23.2, C26.2, C27.2, T1P4.P$1, T2.1, T2.2, TR2.P1, TR3.P2, TR3.S1
DRAIN2: C24.2, C25.2, C28.2, C29.2, T1.1, T1.2, T1S3.P$1, TR2.P2, TR2.S1, TR3.P1
G1: R26.2, R27.2, R28.2, T2.3
G2: R29.2, R30.2, R31.2, T2.4
G3: R32.2, R33.2, R34.2, T1.3
G4: R35.2, R36.2, R37.2, T1.4
GND: C1.1, C2.2, C3.2, C4.2, C5.2, C6.2, C8.2, C9.2, C11.2, C12.2, C13.2, C14.2, C15.1, C16.1, C17.1, C18.1, C19.1, C20.-, C21.-, C22.1, C23.1, C24.1, C25.1, C26.1, C27.1, C28.1, C29.1, C40.-, C41.-, C42.1, C47.1, C48.2, C53.2, C54.2, C55.2, C56.2, C57.2, D4.C, D5.A, D8.C, D9.A, D12.C, D13.A, D15.A, D16.A, H1.P$1, H2.P$1, H3.P$1, H4.P$1, H5.P$1, H6.P$1, H7.P$1, H8.P$1, H9.P$1, H10.P$1, H11.P$1, H12.P$1, H13.P$1, H14.P$1, IC2.2, JP2.1, JP3.1, JP8.1, JP10.1, JP12.1, JP14.1, JP15.1, JP20.1, JP22.1, K2.A2, K3.2, R3.1, R8.1, R9.1, R10.1, R12.1, R15.1, R21.1, R22.1, R23.1, TR1.COM, TR1.GND, TR4.S1
unnamed: JP21.1, R1.1, R2.1
unnamed: C47.2, IC2.1, IC2.3, K2.24
unnamed: D10.C, D13.C
unnamed: JP11.1, K3.P0, K3.P1
unnamed: C1.2, R4.2
unnamed: C2.1, R5.1
unnamed: JP19.1, K2.14
unnamed: C3.1, C4.1, R6.1, R7.2
unnamed: C5.1, C6.1, R7.1, R8.2, R9.2, R10.2, R16.3
unnamed: R12.2, R16.2
unnamed: R13.1, R16.1
unnamed: C48.1, C57.1, IC2.5, R13.2, R24.2
unnamed: D3.C, D5.C
unnamed: D2.A, D4.A
unnamed: C53.1, C54.1, R11.1, R14.2
unnamed: D7.C, D9.C
unnamed: D6.A, D8.A
unnamed: D11.A, D12.A
unnamed: C55.1, C56.1, R14.1, R15.2, R21.2, R22.2, R25.3
unnamed: R23.2, R25.2
unnamed: R24.1, R25.1
unnamed: C10.2, D14.A, R17.2, R18.2, T7.1
unnamed: JP4.1, K3.O0, K3.O1
unnamed: JP9.1, R18.1
unnamed: R19.2, R20.2, TR1.IN
OUTP1: C30.1, C31.1, C32.1, C33.1, C34.1, C45.1, C46.1, TR3.S2
OUTP2: C35.1, C36.1, C37.1, C38.1, C39.1, C43.1, C44.1, TR2.S2
OUTR1: K3.S0, K3.S1, TR4.P1
OUTS1: C30.2, C31.2, C32.2, C33.2, C34.2, C45.2, C46.2, TR4.S2
OUTS2: C35.2, C36.2, C37.2, C38.2, C39.2, C43.2, C44.2, TR4.P2
RELAIS: C42.2, D15.C, JP18.1, K3.1
RELAISOUT: D16.C, JP17.1, K2.A1, T7.3
RFIN: JP1.1, K2.11
U12: C9.1, C10.1, D14.C, JP5.1, K2.21, R17.1, T7.2
UIN: C40.+, JP13.1, JP16.1, L1.P$1
UVERS: C8.1, C11.1, C12.1, C13.1, C14.1, C15.2, C16.2, C17.2, C18.2, C19.2, C20.+, C21.+, C41.+, L1.P$2, T1P3.P$1, T1S4.P$1
